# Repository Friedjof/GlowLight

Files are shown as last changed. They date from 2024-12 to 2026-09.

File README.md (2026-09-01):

# 🌟 GlowLight - Smart Wireless Bedside Lamp





A beautiful, smart bedside lamp with ESP-NOW wireless communication, gesture controls, and multiple lighting modes. Built on ESP32-C3 with 3D-printed components and WS2812B LED strips.

## 📋 Table of Contents

- [✨ Features](#-features)
- [🎭 Available Lighting Modes](#-available-lighting-modes)
- [📸 Gallery](#-gallery)
- [🔗 ESP-NOW Wireless Communication](#-esp-now-wireless-communication)
  - [Configuration](#configuration)
  - [🏠 Home Assistant](#-home-assistant)
- [🔧 Hardware Components](#-hardware-components)
  - [Main Components](#main-components)
  - [3D Printing](#3d-printing)
  - [Soldering](#soldering)
- [🚀 Quick Setup](#-quick-setup)
- [📦 Software Installation (Advanced)](#-software-installation-advanced)
- [👨‍💻 Development](#-development)
  - [Project Structure](#project-structure)
  - [Documentation](#documentation)
  - [Testing](#testing)
  - [Modes](#modes)
- [📄 License](#-license)

## ✨ Features

- **🎨 Multiple Lighting Modes**: Static colors, rainbow, beacon, candle effect, and more
- **⚡ ESP-NOW Communication**: Ultra-fast (<10ms) wireless synchronization between lamps
- **🔐 Encrypted Group Transport**: AES-256-GCM with a shared group key, authenticated peers and replay protection, up to 8 lamps per group
- **🔀 Per-Lamp Sync Control**: Follow and publish are independent switches, so a lamp can go its own way and rejoin later
- **🏠 Home Assistant**: Optional MQTT integration that announces its own entities, generated from the modes in the firmware
- **📶 Optional WiFi**: Infrastructure WiFi alongside ESP-NOW, with a captive portal for provisioning without reflashing
- **⬆️ Password-Protected OTA**: Firmware updates over WiFi with digest authentication and image verification
- **👋 Gesture Control**: Hand proximity sensing with VL53L0X distance sensor
- **🔘 Physical Controls**: Simple button interface for mode switching
- **🏠 3D Printable**: Complete STL files for custom lamp housing
- **🔧 Easy Setup**: One-command installation with interactive configuration
- **📱 Device Management**: Automatic ESP32 detection and flashing
- **💾 Backup System**: Configuration backup and restore

## 🎭 Available Lighting Modes

### Active Modes
- **🎨 StaticMode**: Single solid color with full brightness control
- **🌈 ColorPickerMode**: Cycle through color spectrum with distance sensor
- **🌈 RainbowMode**: Classic flowing rainbow effect with speed control
- **✨ RandomGlowMode**: 10-color random transitions with zen to party speeds
  - *NEW v3.3.0*: Enhanced with 10 scientifically distributed colors (every 36° in HSV space)
  - Features: Pause/transition cycles, inherited brightness control, mesh synchronization
  - Speed modes: Zen (meditative) → Normal → Lebendig (energetic) → Hektisch (party)

### Optional Modes
- **🕯️ CandleMode**: Realistic candle flicker simulation
- **🚨 BeaconMode**: Beacon/alert patterns for notifications
- **🌅 SunsetMode**: Natural sunset simulation for bedtime
- **💫 StrobeMode**: Synchronized strobe effects over ESP-NOW
- **🎮 MiniGame**: Interactive games using distance sensor

> **Note**: Mode selection is declared in `include/ModeConfig.h`. Set an individual
> `GLOW_ENABLE_*` switch to `1`, or use the `esp32c3-all-modes` build profile.

## 📸 Gallery

<table>
  <tr>
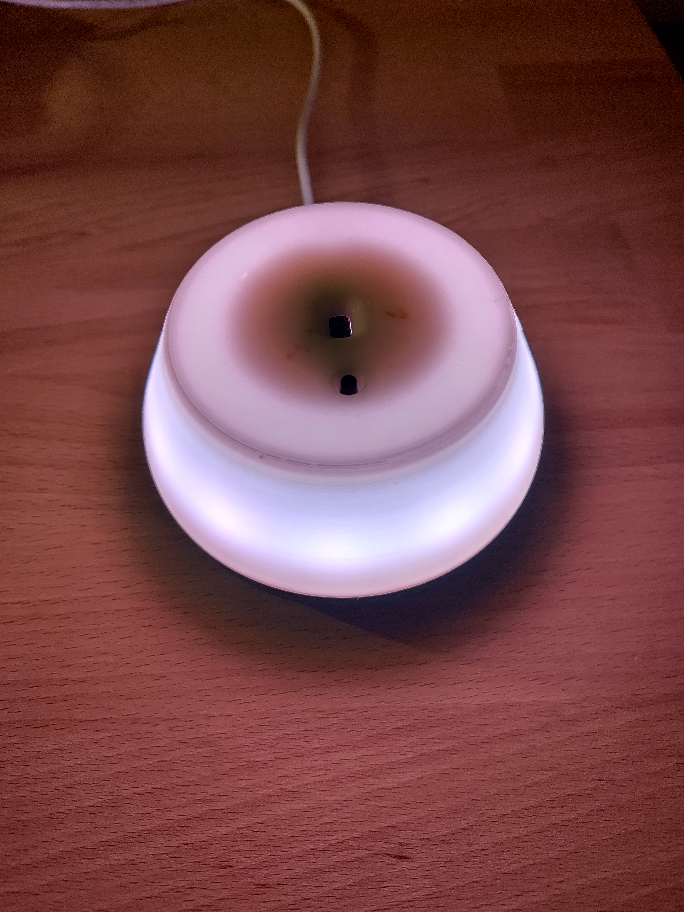
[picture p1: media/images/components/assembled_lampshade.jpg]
Assembled Lampshade
    <td></td>
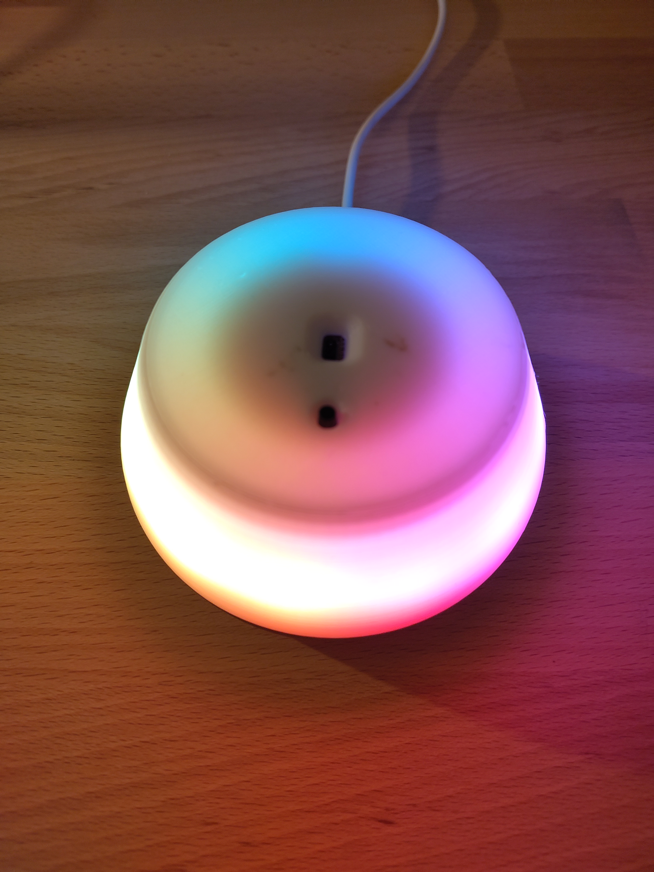
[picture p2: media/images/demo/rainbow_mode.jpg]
Rainbow Mode
    <td></td>
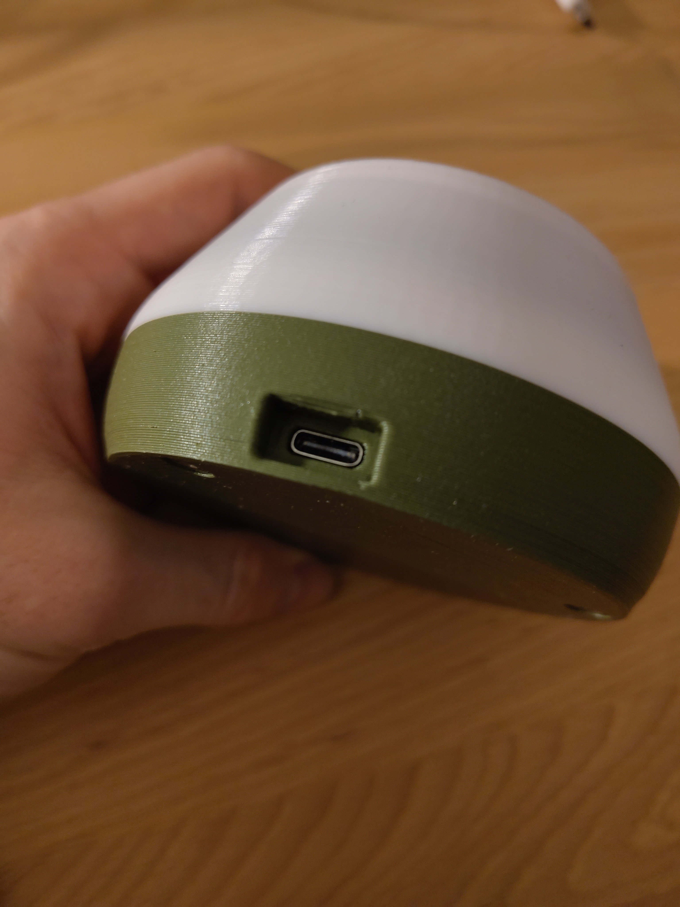
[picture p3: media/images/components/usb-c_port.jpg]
USB-C Port
    <td></td>
  </tr>
</table>

[-> Rainbow Mode Demo Video](media/images/demo/dual_lamps_rainbow_mode.mp4)

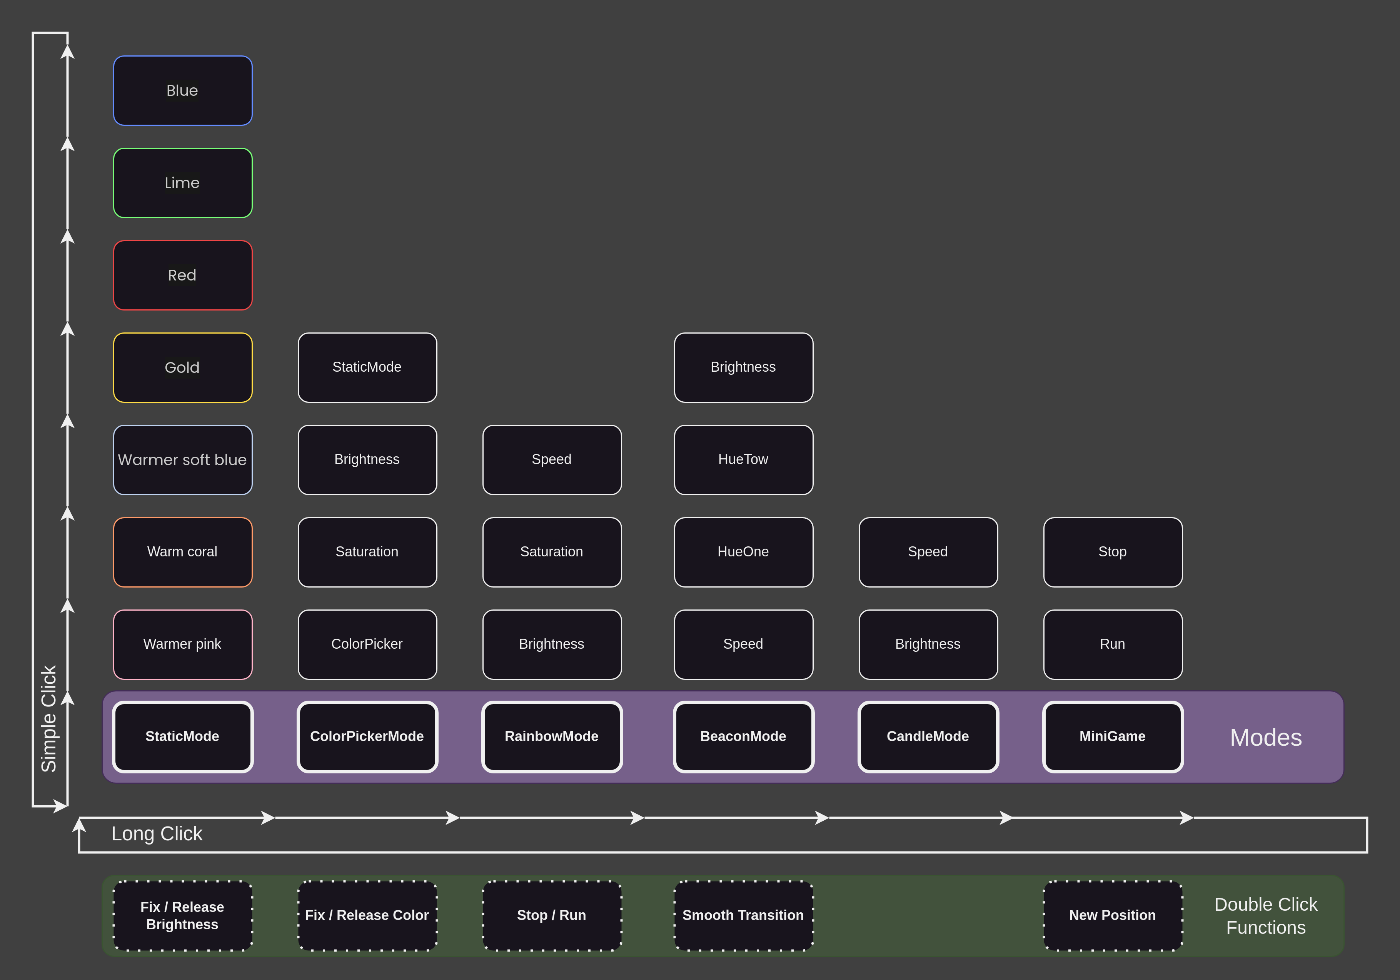
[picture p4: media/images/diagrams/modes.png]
Modes


This is an overview of the different modes available in the lamp. The modes can be toggled using the button.

## 🔗 ESP-NOW Wireless Communication

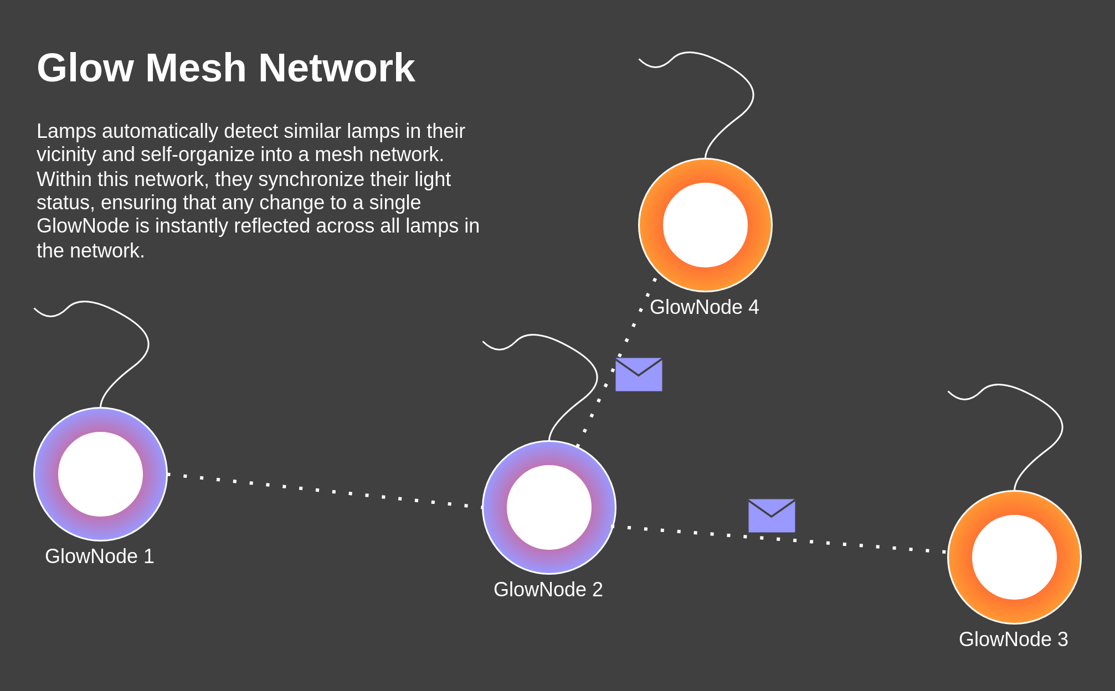
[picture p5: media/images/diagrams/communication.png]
Communication


[-> Wireless Synchronization Demo Video](media/images/demo/3_lamps_communication.mp4)

GlowLight uses **ESP-NOW** for ultra-fast, low-latency wireless communication between lamps. ESP-NOW provides direct device-to-device communication without requiring a WiFi router, enabling instant synchronization across multiple lamps.

### Why ESP-NOW?

- ⚡ **Ultra-low latency**: <10ms message delivery (vs 50-200ms with traditional mesh)
- 🔋 **Energy efficient**: Minimal power consumption compared to WiFi mesh
- 📡 **Simple setup**: No SSID/password configuration needed - just power on
- 🎯 **Reliable**: Direct broadcast communication, no routing overhead
- 📶 **Good range**: Up to 200m line-of-sight
- 🔐 **Encrypted**: AES-256-GCM with a shared group key, up to 8 lamps per group

### Configuration

ESP-NOW broadcasts are not encrypted by the radio, so GlowLight encrypts and
authenticates every frame itself. All lamps of a group share one 256-bit key,
which the setup generates for you:

```bash
./install.sh    # ESP-NOW section: "create" on the first lamp, "join" on the others
```

```cpp
#define WIFI_ON false                  // Optional infrastructure WiFi
#define WIFI_SSID ""
#define WIFI_PASSWORD ""
#define GLOW_HOSTNAME "glowlight"
#define GLOW_PORTAL_ENABLED false       // Hold button during boot to activate
#define GLOW_PORTAL_PASSWORD "..."      // Unique WPA2 password from setup
#define GLOW_OTA_ENABLED false          // Updates over infrastructure WiFi
#define GLOW_OTA_PASSWORD "..."         // Separate unique update password
#define ESPNOW_CHANNEL 1              // WiFi channel (1-13), configurable
#define GLOW_GROUP_KEY_HEX "..."      // 64 hex characters, provisioned by the setup
#define GLOW_MAX_GROUP_NODES 8
#define GLOW_SYNC_FOLLOW_DEFAULT true  // Apply incoming group changes
#define GLOW_SYNC_PUBLISH_DEFAULT true // Publish local group changes
```

`WIFI_ON` is optional; ESP-NOW works without an access point. With WiFi disabled
or unavailable, every lamp parks on `ESPNOW_CHANNEL`. While connected, the access
point dictates the shared radio channel, so all lamps in a group must remain on
the same current channel. Using one access point for all WiFi-enabled lamps is the
simplest guarantee. In a mixed group with WiFi disabled on some lamps, the access
point must use `ESPNOW_CHANNEL`. Reconnect attempts are spread out and, once the
AP channel is known, short and targeted so the fallback channel remains available
for ESP-NOW most of the time.

All lamps must also share the same group key. Lamps with different keys neither
discover nor control each other. Without a valid key wireless synchronization
stays disabled.

See [docs/security.md](docs/security.md) for the security model, key rotation and
migration from older, unencrypted firmware.

Validated NVS configuration overrides these compile-time values. The optional
captive portal is opened only by holding the hardware button during boot and
runs on the ESP-NOW fallback channel without disabling secure group transport.
See [docs/configuration.md](docs/configuration.md) for provisioning, persistence
and the redacted `glow.config/1` API.

Optional OTA updates are available at `http://<hostname>.local/update` only while
infrastructure WiFi is online and require Digest authentication. See
[docs/ota.md](docs/ota.md) for the upload procedure and security boundary.

### 🏠 Home Assistant

A lamp on the WiFi can publish itself to Home Assistant over MQTT and appears
with a light, a mode selector and one control per mode setting — all generated
from the modes the firmware was built with, so nothing has to be configured by
hand. A command from Home Assistant moves the whole lamp group by default. See
[docs/home-assistant.md](docs/home-assistant.md).

### How It Works

1. **Automatic Discovery**: Lamps announce themselves via heartbeat messages (every 10 seconds)
2. **Authentication**: A new lamp is only trusted after answering a fresh challenge, so recorded traffic cannot be replayed in
3. **Instant Sync**: State changes (mode, color, brightness) are broadcast instantly to all lamps in the group
4. **No Infrastructure**: No router, server, or internet connection required
5. **Resilient**: 30-minute timeout removes inactive lamps from the network

Following incoming changes and publishing local changes are independent runtime
controls. They can be changed through the local `glow.control/1`
`sync.configure` operation. Re-enabling follow first requests a versioned state
snapshot and blocks application publishing until the lamp has safely rejoined.
See [docs/control-api.md](docs/control-api.md) for the request and status format.

`NetworkService` owns WiFi mode, access-point reconnects and the shared radio
channel. `CommunicationService` keeps its ESP-NOW broadcast peer on channel `0`
(the radio's current channel) and immediately announces the node after every
stable channel change.

For technical details, see the [CommunicationService README](lib/CommunicationService/README.md).

## 🔧 Hardware Components

- DUBEUYEW ESP32-C3 Development Board Mini
- VL53L0X distance sensor
- Simple push button (height ≥ 6mm)
- WS2812B 5V LED strip (11 LEDs)
- External 5V power supply
- USB-C and some other necessary cables
- 3x M3 threaded insert
- 3x M3 screws

### Main Components

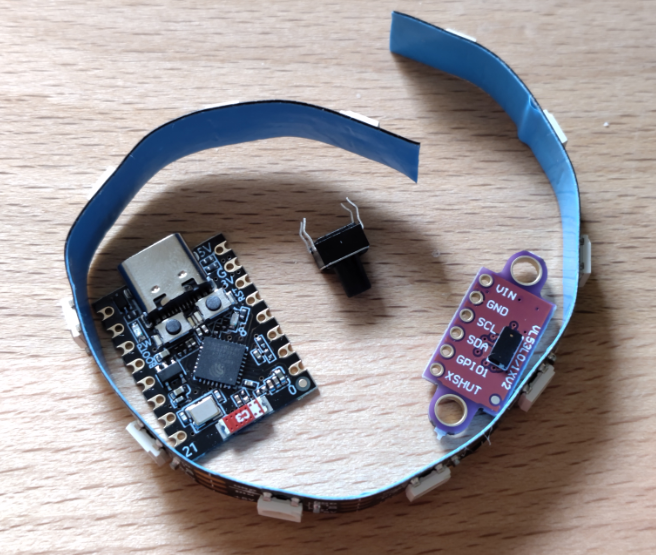
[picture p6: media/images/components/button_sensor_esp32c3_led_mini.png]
Main Components


### Tools and Materials

- 3D printer + filament (white and a color of your choice)
- Soldering iron + solder
- 2x Heat shrink tube
- Screwdriver

### 3D Printing

> You can find the 3D models in the [`/printing`](/printing) folder. The models are designed to be 3D printed and assembled. The lamp consists of three parts: the base, the lampshade, and the lampshade holder.

<table>
  <tr>
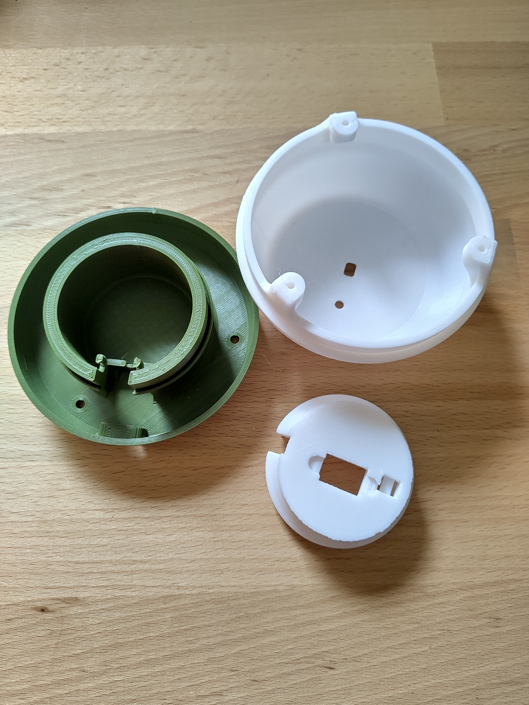
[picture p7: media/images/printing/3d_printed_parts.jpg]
Printed Parts
    <td></td>
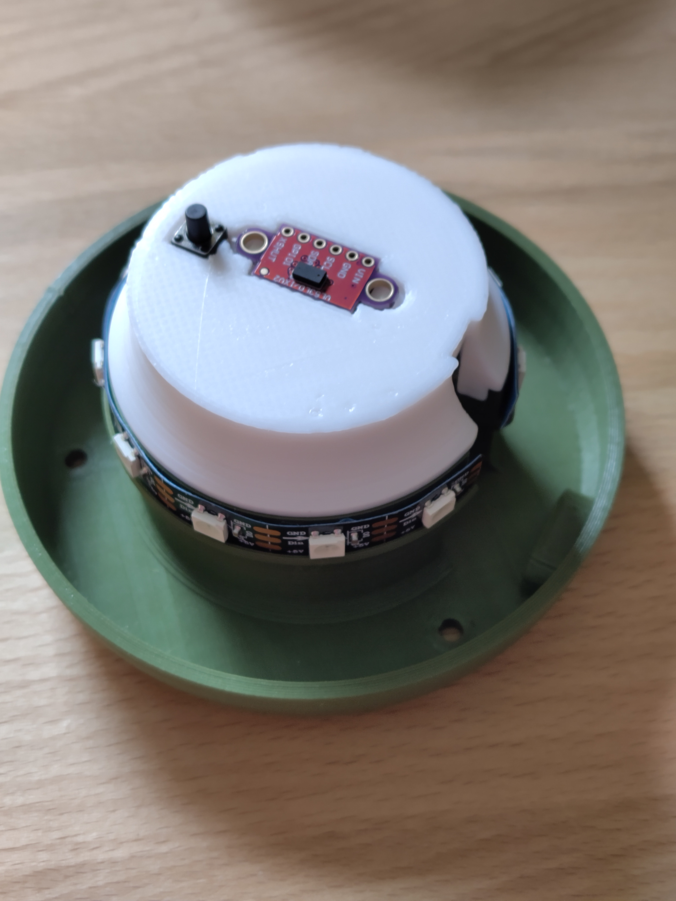
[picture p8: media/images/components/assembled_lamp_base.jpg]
Assembled Lamp Base
    <td></td>
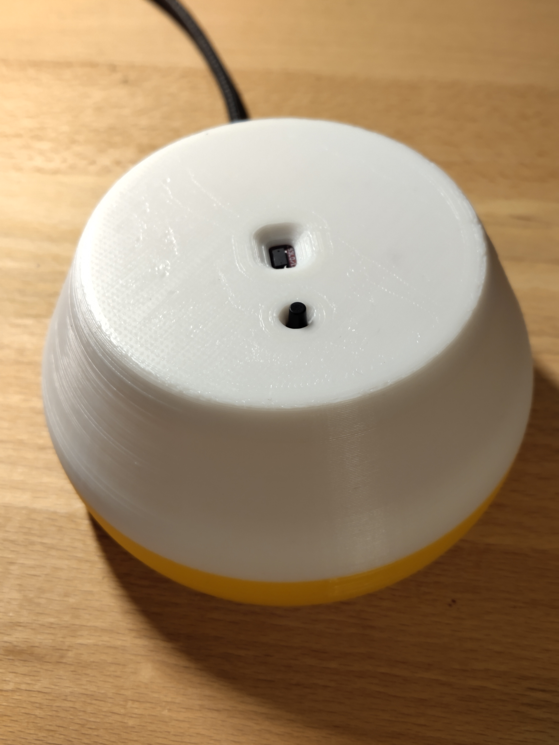
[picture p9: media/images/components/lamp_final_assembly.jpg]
Final Assembly
    <td></td>
  </tr>
</table>

### Soldering

The components are connected to the ESP32C3 using the following diagram:

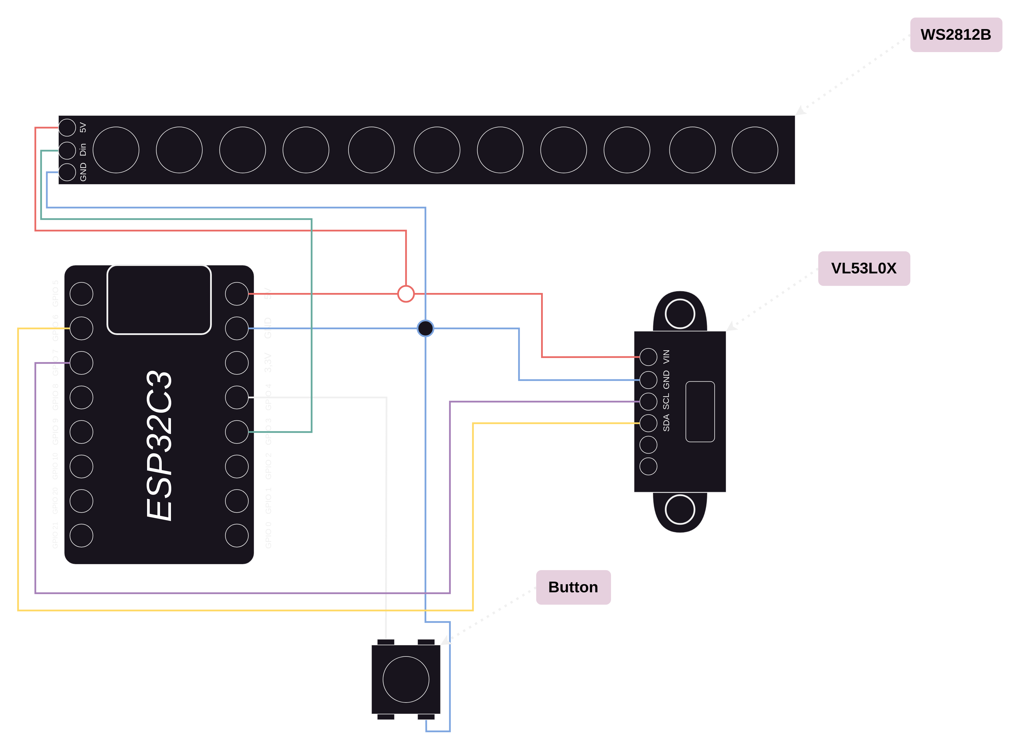
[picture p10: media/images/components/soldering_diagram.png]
Soldering Diagram


> The Button does not require a resistor, as the ESP32C3 has internal pull-up resistors.

This table also shows the connections:

| Component | Pin | ESP32C3 Pin |
| --- | --- | --- |
| Button | 1 | GND |
| | 2 | GPIO 4 |
| VL53L0X | VCC | 5V |
| | GND | GND |
| | SDA | GPIO 6 |
| | SCL | GPIO 7 |
| WS2812B | VCC | 5V |
| | GND | GND |
| | DI  | GPIO 3 |

> The `VL53L0X` is the distance sensor, the `WS2812B` is the LED strip, and the `Button` is the push button.

<table>
  <tr>
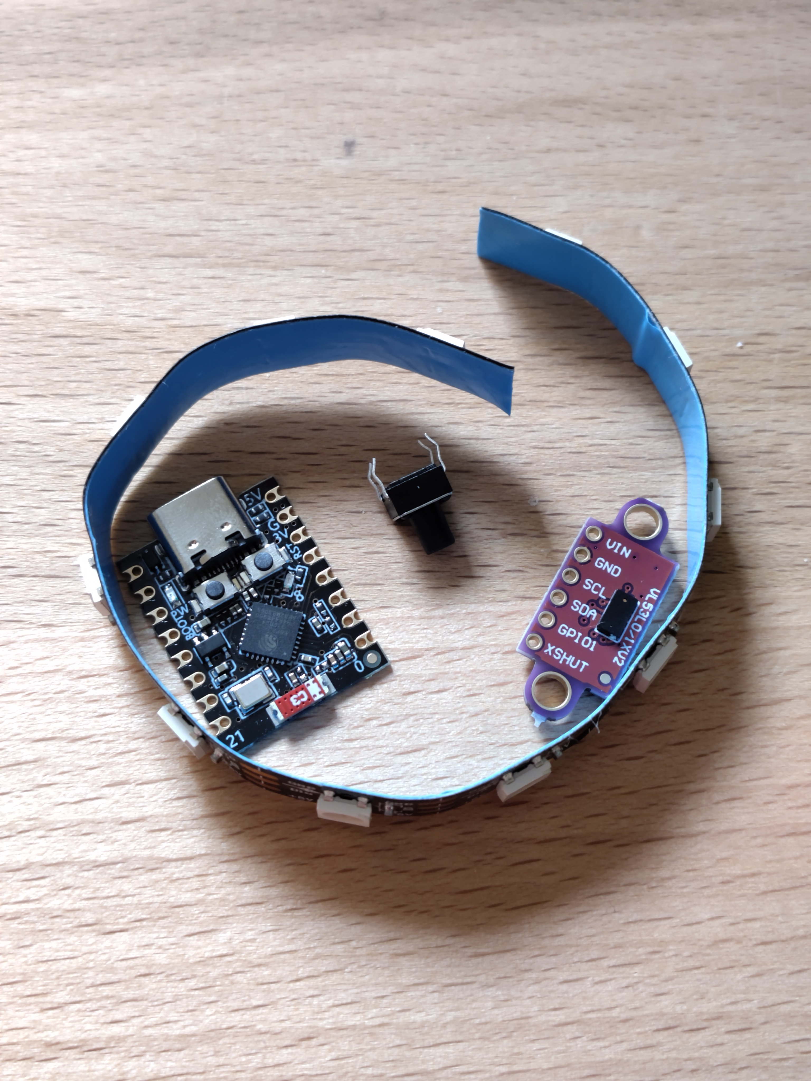
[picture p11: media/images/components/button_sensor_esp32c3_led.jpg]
Button, Sensor, ESP32C3, and LED
    <td></td>
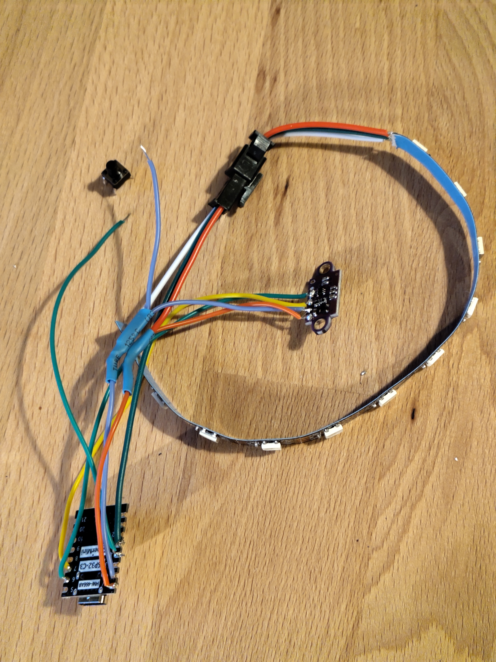
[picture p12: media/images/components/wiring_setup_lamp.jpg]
Wiring Setup
    <td></td>
  </tr>
</table>

### Threaded Insert

To attach the lampshade to the base, a threaded insert is used. The insert is placed in the base, and the lampshade is screwed onto it.

<table>
  <tr>
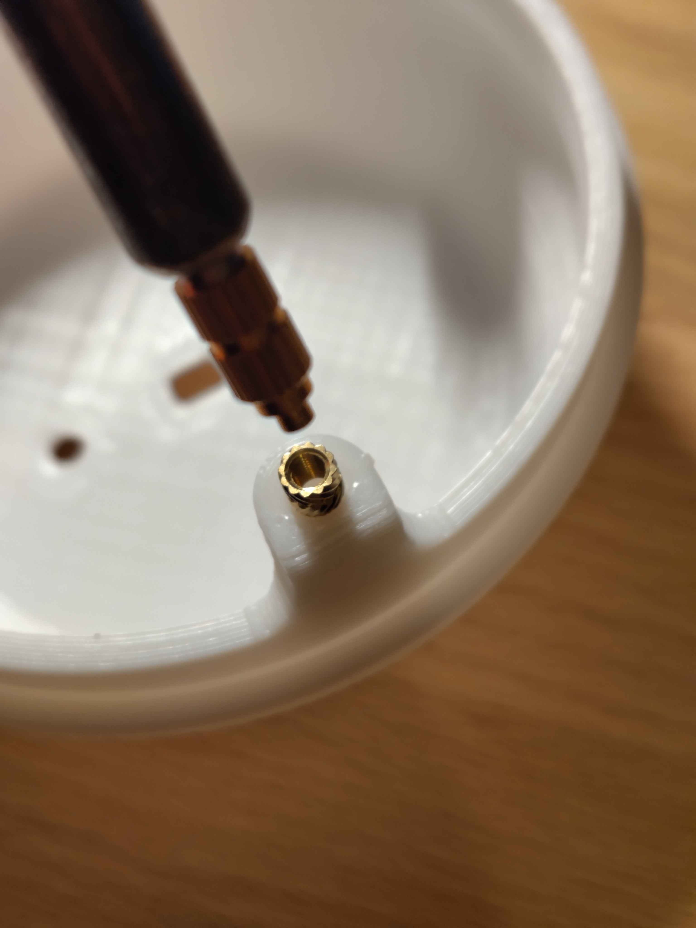
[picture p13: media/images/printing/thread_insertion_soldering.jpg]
Thread Insertion Soldering
    <td></td>
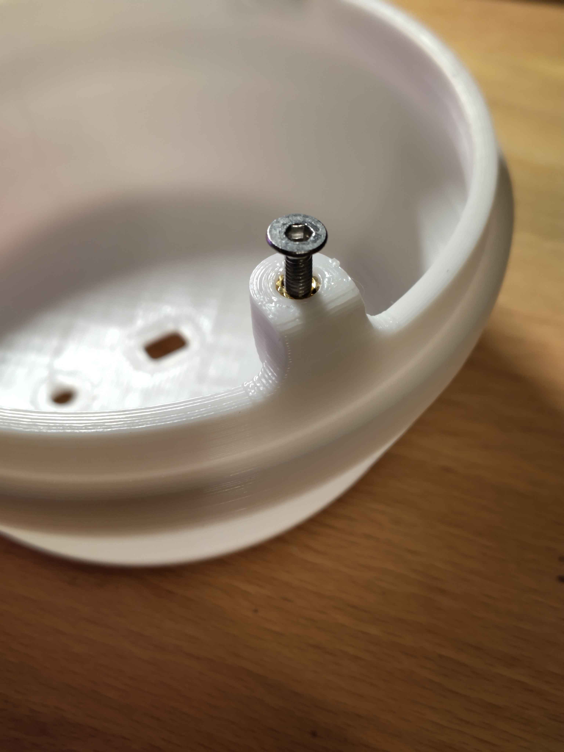
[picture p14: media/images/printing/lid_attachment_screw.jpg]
Lid Attachment Screw
    <td></td>
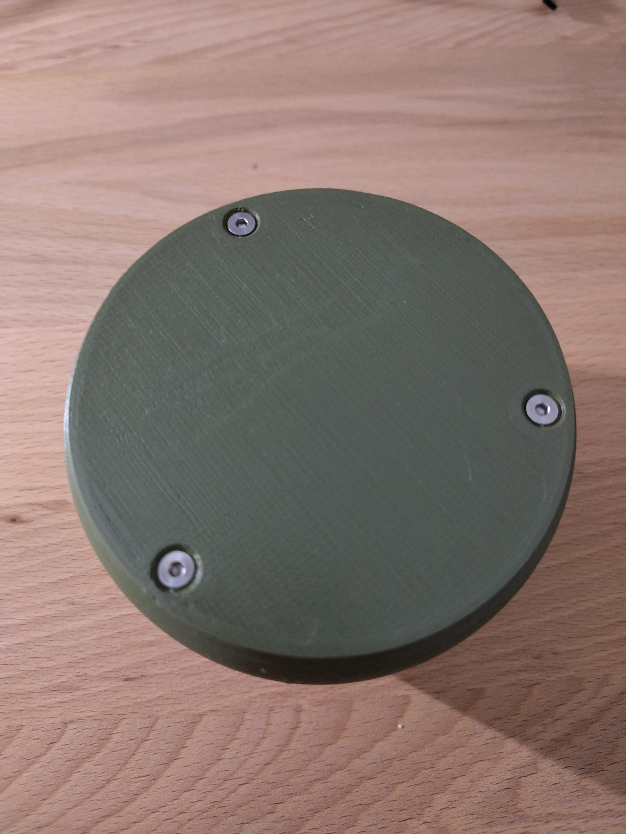
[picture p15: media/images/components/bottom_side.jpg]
Bottom Side
    <td></td>
  </tr>
</table>

## 🚀 Quick Setup

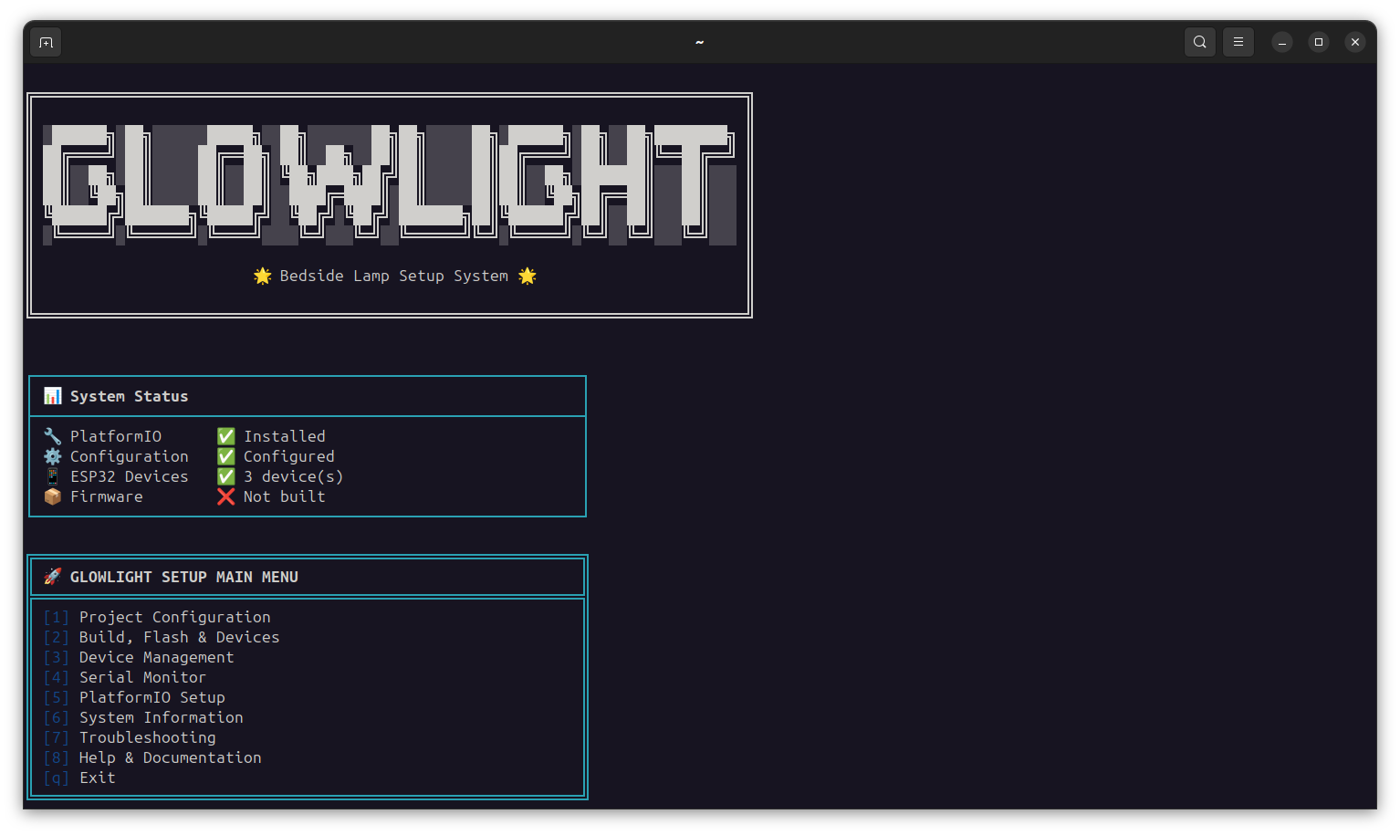
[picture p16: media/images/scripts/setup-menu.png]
Setup Script


**Get started in just one command!** The GlowLight setup system will guide you through the entire installation process:

```bash
curl -fsSL https://raw.githubusercontent.com/friedjof/GlowLight/main/install.sh > install.sh && bash install.sh
```

**Alternative download method:**
```bash
wget https://raw.githubusercontent.com/friedjof/GlowLight/main/install.sh && bash install.sh
```

### What the installer does:

1. **🔍 Checks system requirements** (Python 3.8+, Git)
2. **📦 Installs dependencies** automatically for your OS (Ubuntu/Debian, Fedora, Arch, macOS)
3. **📂 Downloads the GlowLight project** to `~/GlowLight` — unless you run the script from an existing checkout, which is then used as-is
4. **🛠️ Launches the interactive setup system** with a beautiful menu interface

### Interactive Setup Features:

- **⚙️ Project Configuration**: Guided wizards for the group key, captive portal, OTA, WiFi, Home Assistant and GPIO pins
- **🔨 Build & Flash**: Compile and upload firmware to your ESP32-C3 with one click
- **📱 Device Management**: Automatic ESP32 device detection and management
- **📺 Serial Monitor**: Real-time device monitoring with logging
- **🔧 PlatformIO Setup**: Automatic PlatformIO installation and management
- **💾 Backup System**: Configuration backup and restore functionality

### Manual Installation

If you prefer to set up manually:

```bash
# Clone the repository
git clone https://github.com/friedjof/GlowLight.git
cd GlowLight

# Run the setup system
python3 scripts/setup.py
```

## 📦 Software Installation (Advanced)

This is a PlatformIO project. The setup system above handles everything automatically, but for manual installation, PlatformIO must be installed. Once installed, you can open the project in PlatformIO and flash the software onto the ESP32C3.

Alternatively, a `Makefile` is included, allowing you to flash the software via the command line. For this, PlatformIO must be installed, and the `PLATFORMIO` environment variable should point to the PlatformIO executable.

If you're familiar with Nix-shell, you can use the [`shell.nix`](/shell.nix) file to set up the environment for PlatformIO.

### PlatformIO Commands

- `pio run`: Compiles the software
- `pio run --environment esp32c3-all-modes`: Compiles and links every mode
- `pio run --environment esp32c3-integration`: Build with the serial test console
- `pio run --target upload`: Flashes the software to the ESP32C3
- `pio run --target clean`: Removes compiled files
- `pio device monitor`: Opens a terminal to view the ESP32C3 output

### Makefile Commands

Building and flashing:

- `make` or `make build`: Compiles the standard profile
- `make build-all`: Compiles and links every mode
- `make build-profiles`: Builds all three profiles and checks each fits an OTA slot
- `make flash [device-number]`: Flashes the software to the ESP32-C3
- `make flash-all`: Flashes every connected lamp with the same image — this is what puts them into one group
- `make clean`: Removes compiled files
- `make monitor [device-number]`: Opens the serial monitor
- `make run [device-number]`: Flashes the software and opens the monitor
- `make list`: Lists matching ESP32-C3 serial devices

Testing without hardware:

- `make test`: Everything that runs on the host, about a second
- `make test-native`: Protocol, control API and configuration tests against the real firmware sources
- `make test-setup`: Setup, group key handling and the host-side frame format

Testing with hardware:

- `make test-integration`: Group synchronization across all connected lamps
- `make test-isolation`: Two lamps with different keys must ignore each other
- `make test-security KEY=<64 hex>`: Replay and tampering checks against one lamp
- `make test-ota PORT=… HOST=…`: Authenticated firmware update
- `make test-homeassistant BROKER=… DEVICE=… PORT=…`: MQTT integration against a broker

### Libraries Used

- [`ArrayList`](https://registry.platformio.org/libraries/braydenanderson2014/ArrayList) for dynamic arrays
- [`Button2`](https://registry.platformio.org/libraries/lennarthennigs/Button2) for button input handling
- [`Adafruit_VL53L0X`](https://github.com/adafruit/Adafruit_VL53L0X) for the distance sensor
- [`FastLED`](https://registry.platformio.org/libraries/fastled/FastLED) for LED control
- [`ArduinoJson`](https://registry.platformio.org/libraries/bblanchon/ArduinoJson) for message serialization
- [`PubSubClient`](https://registry.platformio.org/libraries/knolleary/PubSubClient) for the optional MQTT connection
- **ESP-NOW**, **WiFi**, **mDNS**, **WebServer**, **Preferences** and **Update** (built-in ESP32 libraries)

For more details on the libraries, refer to the [`platformio.ini`](/platformio.ini) file.

## 👨‍💻 Development

The software is written in C++ and is structured as a typical PlatformIO project. The main file is [`src/main.cpp`](/src/main.cpp), which wires the services together and contains the setup and loop functions. The modes, services, and the controller live in separate libraries under [`/lib`](/lib).

### Project Structure

`Controller` sits between the modes and everything that talks to the outside
world. It derives a machine-readable capability document from what the modes
declare and offers one transport-neutral command surface, so an adapter never
needs to know about a specific mode.

| Library | Responsibility |
|---|---|
| `Controller` | Mode lifecycle, capability document, `glow.control/1` operations, group synchronization policy |
| `AbstractMode`, `GlowRegistry` | Base class for modes; typed settings with bounds and defaults that everything else is generated from |
| `LightService`, `DistanceService` | LED output and the VL53L0X proximity sensor |
| `CommunicationService` | Encrypted ESP-NOW transport: handshake, replay protection, fragmentation |
| `NetworkService` | Owns the shared radio: WiFi state machine, fallback channel, mDNS |
| `ConfigService` | Validated device configuration and its persistence in NVS |
| `CaptivePortalService` | WPA2 setup access point for provisioning without reflashing |
| `OtaService` | Password-protected firmware updates over WiFi |
| `HomeAssistantService` | MQTT adapter; the pure mapping lives in `HomeAssistantProtocol` |

Adding a mode does not touch any of the services: declare its options and
registry keys as before, register it in `src/ModeRegistration.cpp`, and it shows
up in the control API and in Home Assistant on its own.

### Documentation

- [Control API](docs/control-api.md) — capability document and JSON command surface
- [Configuration](docs/configuration.md) — provisioning, NVS persistence, captive portal
- [Security](docs/security.md) — threat model, key handling, migration from older firmware
- [Home Assistant](docs/home-assistant.md) — MQTT integration, topics, entity generation
- [OTA Updates](docs/ota.md) — upload procedure and security boundary
- [Technical Diagrams](docs/diagrams.md) — architecture and flow diagrams

### Testing

`make test` runs everything that needs no hardware. The protocol tests compile
the real `CommunicationService` on the host against thin shims for Arduino,
ESP-NOW, FreeRTOS and mbedTLS, and drive it with frames built by an independent
implementation — so the firmware and the test oracle cannot drift apart quietly.

The hardware runners in [`test/hil`](/test/hil) cover group synchronization,
group isolation, replay and tampering, OTA and the Home Assistant integration.
See [test/README](/test/README) for what each one checks and what it needs.

### Technical Diagrams

For a comprehensive understanding of the GlowLight system architecture and operation, see the [Technical Diagrams](docs/diagrams.md) which includes:

- **[Class Diagram](docs/diagrams.md#class-diagram)**: Complete class structure and relationships
- **[Main Program Flow](docs/diagrams.md#main-program-flow)**: Startup sequence and main loop execution
- **[Mode System Flow](docs/diagrams.md#mode-system-flow)**: Lighting modes management and switching
- **[Service Integration Flow](docs/diagrams.md#service-integration-flow)**: LightService, DistanceService, and CommunicationService interaction
- **[Button Interaction Flow](docs/diagrams.md#button-interaction-flow)**: Button press handling and mode switching logic
- **[ESP-NOW Communication Flow](docs/diagrams.md#esp-now-communication-flow)**: Wireless networking and synchronization
- **[Available Modes Detail](docs/diagrams.md#available-modes-detail)**: Overview of all lighting modes and their features

### Modes

Every mode is a class that inherits from the `AbstractMode` class. The abstract class already implements the basic functions that every mode should have. In every mode, the following functions must be implemented: `setup`, `customFirst`, `customLoop`, `last`, and `customClick`.

- `setup`: This function is called once when the mode is added to the controller when the lamp is turned on.
- `customFirst`: This function is called once when the mode is newly selected.
- `customLoop`: This function is called every loop iteration.
- `last`: This function is called once when the mode is removed from the controller.
- `customClick`: This function is called when a double click is detected from the button.

The constructor sets `title` for display and `id` as the stable protocol
identifier. The ID appears in group messages, in the control API and in MQTT
topics, so it must not change once lamps are in the field; the display name may.

Everything a mode declares in `setup` is what the rest of the system works from:

- `registry.init(key, type, default, min, max)` defines a setting. Its type and
  bounds become validation for remote changes and, in Home Assistant, a number,
  a switch or a text field.
- `addOption(title, callback)` registers an option, which becomes a selectable
  entry both on the button and in the control API.
- `declareCommand(name, arguments)` exposes a mode-specific action that peers and
  adapters may invoke.

Optional hooks exist for modes that need to react to state arriving from
elsewhere: `onStateApplied` after a complete state was adopted,
`onSettingChanged` for a single value, and `onStateActivated` when the mode
becomes active with restored state. Simple modes need none of them.

## 📄 License

This project is licensed under the GNU General Public License v3.0. For more information, see the [`LICENSE`](/LICENSE) file.

---

## ⚠️ Beta Notice

This is a beta version of the project. The software is still under development, and the hardware may require some adjustments. I cannot guarantee that the project will work as expected and will not be responsible for any damage caused by the project.

## 🎯 Quick Start Reminder

**New to GlowLight?** Get started with just one command:

```bash
curl -fsSL https://raw.githubusercontent.com/friedjof/GlowLight/main/install.sh | bash
```

The setup system will guide you through everything! 🚀

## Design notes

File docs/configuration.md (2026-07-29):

# Runtime Configuration and Captive Portal

GlowLight loads network, radio, group and synchronization defaults from NVS at
boot. If NVS has no valid record, the values in `include/GlowConfig.h` are used.
If neither source validates, the firmware fails closed with infrastructure WiFi
and group communication disabled on fallback channel 1.

Hardware pins, compiled lighting modes, queue sizes and maximum group size remain
build-time configuration.

## Stored Configuration

The `glow.config` schema contains:

- infrastructure WiFi enabled state, SSID, password and hostname

Lamps are usually flashed from one shared configuration, so a hostname left at its
default is not unique. Each lamp therefore appends the last three bytes of its MAC,
giving names like `glowlight-52c82c`. It announces the result as
`Reachable as <name>.local`, and that name is also the device name in Home Assistant.
A hostname entered in the captive portal belongs to that one lamp and is used as
given.
- ESP-NOW fallback channel
- secure group communication enabled state and 256-bit group key
- default `follow` and `publish` synchronization policy
- OTA enabled state and write-only OTA password

The `PreferencesConfigStore` keeps two CRC-protected slots in the `glowcfg` NVS
namespace. A save writes the older slot with a higher generation and verifies it
before reporting success. At boot the highest valid generation wins; a corrupt or
partially written slot is ignored as a whole.

NVS persistence does not imply flash encryption. A person with physical flash
access can recover stored WiFi, group and OTA credentials unless ESP32 flash/NVS
encryption is enabled for the product.

## Opening the Portal

The installer can enable the portal and generates an individual WPA2 password.
With the feature enabled:

1. Disconnect power from the lamp.
2. Hold the lamp button.
3. Apply power and keep the button held during boot.
4. Join `<hostname>-setup` using the generated portal password.
5. Open `http://192.168.4.1/` if the operating system does not open the captive
   page automatically. The actual address is printed on the serial console.

The portal never opens merely because an infrastructure access point is down and
automatically restarts the lamp after ten minutes.
It runs in `WIFI_AP_STA` mode on the configured fallback channel, leaves modem
sleep disabled and does not deinitialize ESP-NOW. Existing secure group
communication therefore remains available to lamps on the same channel.

An ESP32-C3 has one radio. A peer connected to an infrastructure access point on
a different channel cannot communicate with the provisioning lamp until both are
again on the same channel.

## Configuration API

The portal exposes `glow.config/1` only while the physically activated setup AP
is running:

```text
GET  /api/config
POST /api/config
POST /api/factory-reset
```

`GET /api/config` returns redacted state and a per-boot CSRF `sessionToken`. WiFi
passwords and group keys are never returned. Mutating requests require that token
in the `X-Glow-Token` header. Access authentication is provided by the individual
WPA2 portal password; the token prevents cross-origin form submission. An empty
password or key field preserves the stored secret.

```json
{
  "api": "glow.config/1",
  "wifi": {
    "enabled": true,
    "ssid": "home",
    "password": "write-only",
    "hostname": "glow-bedroom"
  },
  "radio": {"fallbackChannel": 6},
  "group": {
    "enabled": true,
    "key": "64 hexadecimal characters, write-only",
    "follow": true,
    "publish": true
  },
  "ota": {"enabled": true, "password": "write-only"}
}
```

Updates are validated and stored atomically, then the lamp restarts. Active
WiFi credentials and group keys are never replaced live. Factory reset clears
NVS overrides and restarts into the compile-time configuration.

The portal deliberately does not expose `Controller::executeControl()`. The
configuration AP and session token protect provisioning, but are not a general
authorization mechanism for lamp control.

OTA credentials are independent from the portal credentials. An empty OTA
password preserves the existing value. See [ota.md](ota.md) for update behavior
and its trusted-network security boundary.

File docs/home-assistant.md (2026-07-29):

# Home Assistant

A lamp on the infrastructure WiFi can publish itself to Home Assistant over MQTT.
It announces its own entities, so nothing has to be configured in Home Assistant
by hand, and no YAML is involved.

## What you need

- The lamp joined to your WiFi (see [configuration.md](configuration.md))
- An MQTT broker Home Assistant already talks to, usually the Mosquitto add-on
- The MQTT integration enabled in Home Assistant

## Enabling it

Either in the setup before flashing:

```bash
./install.sh     # step "Home Assistant"
```

or later through the captive portal, which stores the settings in NVS and needs
no reflash. Both ask for broker host, port, optional credentials and the
discovery prefix (`homeassistant` unless you changed it in Home Assistant).

Home Assistant requires infrastructure WiFi. Enabling MQTT without WiFi is
rejected by the configuration validator rather than silently ignored.

## What appears

Every lamp becomes one device, identified by `glow-<node id>`, which is derived
from its MAC. Device id, base topic, MQTT client id and every entity id are
therefore unique even though all lamps are flashed from the same configuration.

The device **name** follows the hostname, which for the same reason gets the last
three MAC bytes appended unless you named the lamp yourself in the portal. So the
lamps appear as `glowlight-52c82c`, `glowlight-9d6fc0` and so on. Rename them in
Home Assistant to whatever suits the room; that only changes the display name.

The entities are generated from what the modes declare, so a firmware with more
modes simply offers more entities:

| Entity | Comes from |
|---|---|
| Light (on/off, brightness) | the `brightness` value every mode inherits |
| Mode (select) | the list of modes in the firmware |
| *Mode* option (select) | the options a mode registered, one entity per mode |
| One control per setting | every writable registry key of a mode |
| Follow group, Publish to group (switches) | the two synchronization controls |
| Sync status (sensor) | the runtime synchronization state |

An integer setting becomes a number with the declared minimum and maximum, a
boolean becomes a switch, a string becomes a text field. Entities that belong to
a mode are marked unavailable while another mode is active, so the dashboard only
shows what is actually adjustable right now.

The full state document is published to `glowlight/<device>/state` and attached
to the sync status sensor as attributes, which is the place to look when you want
to template on something that has no entity of its own.

### Colour

The light entity carries brightness only. Colour differs too much between modes —
one mode has an RGB value, another has hue and saturation — so it is exposed as
the individual settings of the active mode rather than guessed into one entity.
A template light in Home Assistant can combine them if you want a single control.

## Groups

By default a command from Home Assistant applies to the whole lamp group: change
the mode on one lamp and the others follow over ESP-NOW. That only happens while
the lamp is actually synchronized and allowed to publish. If it is detached, or
still joining, the command applies to that lamp alone instead of failing. The
`Follow group` and `Publish to group` switches decide which of the two it is.

This means one lamp is enough to control a whole group from Home Assistant. If
you want each lamp separately, switch `Publish to group` off on the lamps that
should keep to themselves.

## Topics

```
glowlight/<device>/status                     online | offline (last will)
glowlight/<device>/state                      full state document
glowlight/<device>/light/state | /set
glowlight/<device>/mode/state  | /set
glowlight/<device>/mode/<mode>/available
glowlight/<device>/option/<mode>/state | /set
glowlight/<device>/setting/<mode>/<key>/state | /set
glowlight/<device>/sync/follow/state  | /set
glowlight/<device>/sync/publish/state | /set
glowlight/<device>/sync/status
```

`<device>` is `glow-<node id>`. Discovery documents are retained under
`<discovery prefix>/<component>/<device>/<object>/config`.

## Security

- Broker credentials live in NVS once set through the portal, not in the image.
- The group key, the OTA password and the broker password are never published;
  a test asserts that no generated payload contains them.
- MQTT itself is unauthenticated towards the lamp: anyone who can publish to the
  broker can control the lamp. Restrict broker access accordingly — the lamp
  trusts the broker the same way it trusts the local network for OTA.
- The connection is plain MQTT. Use it on a network you control.

## Limitations

- Reconnecting to an unreachable broker briefly blocks the main loop, because the
  MQTT client connects synchronously. The retry interval backs off to a minute,
  so a broker that is down causes a short hitch at most once per minute.
- Discovery is published once per connection. If you delete entities in Home
  Assistant, restart the lamp to have them announced again.

## Testing

```bash
pip install paho-mqtt
make test-homeassistant BROKER=mqtt.local DEVICE=glow-1384610827 PORT=/dev/ttyACM0
```

Add `PEER_PORT=/dev/ttyACM1` to also verify that a command sent to one lamp
reaches the second one over ESP-NOW.

The mapping itself is covered by host tests in `test/native/tests_homeassistant.cpp`,
including a mode the MQTT layer has never heard of, which has to appear in
discovery with its options and settings anyway.

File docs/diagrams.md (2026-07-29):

# GlowLight - Technical Diagrams

This document contains all technical diagrams for the GlowLight Smart Mesh Bedside Lamp project, including class relationships and program flow visualizations.

## Table of Contents

- [Class Diagram](#class-diagram)
- [Program Flow Diagrams](#program-flow-diagrams)
  - [Main Program Flow](#main-program-flow)
  - [Mode System Flow](#mode-system-flow)
  - [Service Integration Flow](#service-integration-flow)
  - [Button Interaction Flow](#button-interaction-flow)
  - [Mesh Communication Flow](#mesh-communication-flow)
  - [Available Modes Detail](#available-modes-detail)

## Class Diagram

This diagram shows the complete class structure and relationships within the GlowLight system.

```mermaid
classDiagram
    %% Main entry point
    class main {
        +Controller controller
        +LightService lightService
        +CommunicationService communicationService
        +DistanceService distanceService
        +GlowRegistry glowRegistry
        +setup()
        +loop()
    }

    %% Core Controller
    class Controller {
        -LightService* lightService
        -CommunicationService* communicationService
        -DistanceService* distanceService
        -GlowRegistry* glowRegistry
        -bool isButtonPressed
        -unsigned long lastButtonTime
        +setup(LightService*, CommunicationService*, DistanceService*, GlowRegistry*)
        +loop()
    }

    %% Services
    class LightService {
        -CRGB leds[LED_NUM_LEDS]
        -CRGB currentLeds[LED_NUM_LEDS]
        -uint8_t hardwareBrightness
        -uint16_t lightUpdateSteps
        -bool outputDirty
        +setup()
        +loop()
        +setHardwareBrightness(uint8_t)
        +fill(CRGB)
        +setLed(uint8_t, CRGB)
        +fillImmediate(CRGB)
        +setLedImmediate(uint8_t, CRGB)
    }

    class CommunicationService {
        -bool connected
        -uint8_t peerList[MAX_PEERS][6]
        -int peerCount
        +setup()
        +loop()
        +sendAlert(Alert*)
        +scanForPeers()
        -setupESPNow()
        -addPeer()
    }

    class DistanceService {
        +setup()
        +getDistance()
    }

    class GlowRegistry {
        -AbstractMode* modes[MAX_MODES]
        -const char* modeNames[MAX_MODES]
        -int modeCount
        -int currentModeIndex
        -Preferences preferences
        +setup()
        +registerMode(const char*, AbstractMode*)
        +getMode(const char*)
        +getNextMode()
        +setCurrentMode(int)
        +getCurrentModeName()
    }

    %% Abstract Mode Interface
    class AbstractMode {
        <<abstract>>
        #uint8_t desiredBrightness
        +updateBrightnessFromSensor()
        +setDesiredBrightness(uint8_t)
        +getDesiredBrightness()
        +setup()*
        +customLoop()*
    }

    %% Concrete Mode Implementations
    class StaticMode {
        +setup()
        +update(CRGB*, int)
        +reset()
    }

    class RainbowMode {
        -uint8_t hue
        -uint8_t deltaHue
        +setup()
        +update(CRGB*, int)
        +reset()
    }

    class CandleMode {
        +setup()
        +update(CRGB*, int)
        +reset()
    }

    class RandomGlowMode {
        +setup()
        +update(CRGB*, int)
        +reset()
    }

    class SunsetMode {
        +setup()
        +update(CRGB*, int)
        +reset()
    }

    class StrobeMode {
        +setup()
        +update(CRGB*, int)
        +reset()
    }

    class BeaconMode {
        +setup()
        +update(CRGB*, int)
        +reset()
    }

    class ColorPickerMode {
        +setup()
        +update(CRGB*, int)
        +reset()
    }

    %% Helper Classes
    class Alert {
        -AlertType type
        -char message[256]
        -unsigned long timestamp
        +Alert(AlertType, const char*)
        +getType()
        +getMessage()
        +getTimestamp()
    }

    %% Relationships
    main --> Controller : creates
    main --> LightService : creates
    main --> CommunicationService : creates
    main --> DistanceService : creates
    main --> GlowRegistry : creates

    Controller --> LightService : uses
    Controller --> CommunicationService : uses
    Controller --> DistanceService : uses
    Controller --> GlowRegistry : uses

    LightService --> AbstractMode : uses current mode
    CommunicationService --> Alert : sends/receives
    GlowRegistry --> AbstractMode : manages all modes

    AbstractMode <|-- StaticMode : implements
    AbstractMode <|-- RainbowMode : implements
    AbstractMode <|-- CandleMode : implements
    AbstractMode <|-- RandomGlowMode : implements
    AbstractMode <|-- SunsetMode : implements
    AbstractMode <|-- StrobeMode : implements
    AbstractMode <|-- BeaconMode : implements
    AbstractMode <|-- ColorPickerMode : implements
```

## Program Flow Diagrams

### Main Program Flow

This diagram shows the complete program execution from system startup through the main loop.

```mermaid
flowchart TD
    A[System Start] --> B[setup Function]
    B --> C[Serial.begin 115200]
    C --> D[Wire.begin I2C Setup]
    D --> E[Services Setup]
    E --> E1[lightService.setup]
    E --> E2[distanceService.setup]
    E --> E3[networkService.setup]
    E --> E4[communicationService.setup]
    E1 --> F[Button Setup]
    E2 --> F
    E3 --> F
    E4 --> F
    F --> F1[button.begin BUTTON_PIN]
    F1 --> F2[button.setLongClickTime 500]
    F2 --> G[Mode Registration]
    G --> G1[controller.addMode staticMode]
    G1 --> G2[controller.addMode colorPickerMode]
    G2 --> G3[controller.addMode rainbowMode]
    G3 --> G4[controller.addMode randomGlowMode]
    G4 --> H[Alert Mode Setup]
    H --> H1[controller.setAlertMode alertMode]
    H1 --> I[controller.setup]
    I --> J[Button Handler Setup]
    J --> J1[setLongClickHandler nextMode]
    J1 --> J2[setClickHandler nextOption]
    J2 --> J3[setDoubleClickHandler customClick]
    J3 --> K[Setup Complete]
    K --> L[loop Function Infinite Loop]
    L --> M[Service Loop Calls]
    M --> M1[button.loop]
    M --> M2[controller.loop]
    M --> M3[lightService.loop]
    M --> M4[distanceService.loop]
    M --> M5[networkService.loop]
    M --> M6[communicationService.loop]
    M1 --> N{Button Event?}
    M2 --> O{Distance Change?}
    M3 --> P{LED Update?}
    M4 --> Q{Mesh Message?}
    M5 --> R[Update LEDs]
    N -->|Long Click| N1[controller.nextMode]
    N -->|Single Click| N2[controller.nextOption]
    N -->|Double Click| N3[controller.customClick]
    N -->|No Event| R
    O -->|Yes| O1[Process Distance Data]
    O -->|No| R
    O1 --> O2{ColorPicker Mode?}
    O2 -->|Yes| O3[Update Color Based on Distance]
    O2 -->|No| R
    P -->|Yes| P1[FastLED.show]
    P -->|No| R
    Q -->|Yes| Q1[Process Mesh Data]
    Q -->|No| R
    Q1 --> Q2[Synchronize with Other Lamps]
    N1 --> R
    N2 --> R
    N3 --> R
    O3 --> R
    P1 --> R
    Q2 --> R
    R --> L
```

### Mode System Flow

This diagram illustrates how lighting modes are managed, switched, and executed.

```mermaid
flowchart TD
    A[Mode System Start] --> B[Controller Setup]
    B --> C[Mode Array Initialization]
    C --> D[Current Mode = staticMode]
    D --> E{Button Long Click?}
    E -->|Yes| F[controller.nextMode]
    E -->|No| G{Button Single Click?}
    F --> F1[currentModeIndex++]
    F1 --> F2{Index >= modeCount?}
    F2 -->|Yes| F3[currentModeIndex = 0]
    F2 -->|No| F4[Switch to New Mode]
    F3 --> F4
    F4 --> F5[oldMode.last]
    F5 --> F6[newMode.setup]
    F6 --> F7[newMode.customFirst]
    F7 --> H[Mode Active]
    G -->|Yes| I[controller.nextOption]
    G -->|No| J{Button Double Click?}
    I --> I1[currentMode.nextOption]
    I1 --> H
    J -->|Yes| K[controller.customClick]
    J -->|No| H
    K --> K1[currentMode.customClick]
    K1 --> H
    H --> L[Mode Loop Execution]
    L --> L1[currentMode.customLoop]
    L1 --> L2[Update LEDs]
    L2 --> M{Distance Sensor Active?}
    M -->|Yes| N[Process Distance Input]
    M -->|No| O{Mesh Message?}
    N --> N1{ColorPicker Mode?}
    N1 -->|Yes| N2[Map Distance to Color]
    N1 -->|No| O
    N2 --> O
    O -->|Yes| P[Synchronize Mode State]
    O -->|No| Q[Continue Loop]
    P --> Q
    Q --> E
```

### Service Integration Flow

This diagram shows how the three core services interact with each other and the controller.

```mermaid
flowchart TD
    A[Service Integration] --> B[LightService]
    A --> C[DistanceService]
    A --> D[CommunicationService]
    B --> B1[FastLED Setup]
    B1 --> B2[LED Array Initialization]
    B2 --> B3[Default Brightness Setup]
    B3 --> B4{Mode Update Required?}
    B4 -->|Yes| B5[Update LED Colors]
    B4 -->|No| B6[FastLED.show]
    B5 --> B6
    B6 --> B7[Wait for Next Update]
    B7 --> B4
    C --> C1[VL53L0X Sensor Setup]
    C1 --> C2[I2C Communication Setup]
    C2 --> C3{Distance Reading Request?}
    C3 -->|Yes| C4[Read Sensor Data]
    C3 -->|No| C5[Wait]
    C4 --> C6[Process Distance Value]
    C6 --> C7{Valid Reading?}
    C7 -->|Yes| C8[Return Distance]
    C7 -->|No| C9[Return Error Value]
    C8 --> C5
    C9 --> C5
    C5 --> C3
    D --> D1[ESP-NOW Setup]
    D1 --> D2[Mesh Network Join]
    D2 --> D3[Peer Discovery]
    D3 --> D4{Mesh Message Received?}
    D4 -->|Yes| D5[Parse Message]
    D4 -->|No| D6{Send Message Required?}
    D5 --> D7{Mode Sync Message?}
    D7 -->|Yes| D8[Update Local Mode]
    D7 -->|No| D9[Process Other Message]
    D8 --> D6
    D9 --> D6
    D6 -->|Yes| D10[Broadcast to Mesh]
    D6 -->|No| D11[Continue]
    D10 --> D11
    D11 --> D4
    B8[LED Update Event] --> E[Controller Integration]
    C10[Distance Change Event] --> E
    D12[Mesh Sync Event] --> E
    E --> F{Event Type?}
    F -->|LED Update| G[Update Current Mode Display]
    F -->|Distance Change| H[Process Distance for Current Mode]
    F -->|Mesh Sync| I[Synchronize Mode State]
    G --> J[Services Continue]
    H --> J
    I --> J
    J --> B4
    J --> C3
    J --> D4
```

### Button Interaction Flow

This diagram details the button press handling and resulting actions.

```mermaid
flowchart TD
    A[Button Press Detected] --> B{Button Type?}
    B -->|Long Click 500ms+| C[nextMode]
    B -->|Single Click| D[nextOption]
    B -->|Double Click| E[customClick]
    C --> C1[Increment Mode Index]
    C1 --> C2{Index Overflow?}
    C2 -->|Yes| C3[Reset to First Mode]
    C2 -->|No| C4[Select New Mode]
    C3 --> C4
    C4 --> C5[Call currentMode.last]
    C5 --> C6[Call newMode.setup]
    C6 --> C7[Call newMode.customFirst]
    C7 --> F[Mode Switched]
    D --> D1[Call currentMode.nextOption]
    D1 --> D2[Mode-Specific Option Change]
    D2 --> G[Option Changed]
    E --> E1[Call currentMode.customClick]
    E1 --> E2[Mode-Specific Custom Action]
    E2 --> H[Custom Action Executed]
    F --> I[Continue Loop]
    G --> I
    H --> I
    I --> A
```

### Mesh Communication Flow

This diagram shows the ESP-NOW mesh networking and synchronization process.

```mermaid
flowchart TD
    A[Mesh Communication Start] --> B[ESP-NOW Initialization]
    B --> C[Peer Discovery]
    C --> D[Network Formation]
    D --> E{Message Type?}
    E -->|Incoming| F[Receive Message]
    E -->|Outgoing| G[Send Message]
    E -->|None| H[Idle State]
    F --> F1[Parse Message Header]
    F1 --> F2{Message Type?}
    F2 -->|Mode Sync| F3[Synchronize Mode]
    F2 -->|Alert| F4[Process Alert]
    F2 -->|Status| F5[Update Status]
    F3 --> I[Apply Changes]
    F4 --> I
    F5 --> I
    G --> G1[Prepare Message]
    G1 --> G2[Add Timestamp]
    G2 --> G3[Broadcast to Peers]
    G3 --> J[Message Sent]
    H --> K[Monitor Network]
    K --> L{Network Change?}
    L -->|Yes| C
    L -->|No| E
    I --> M[Update Local State]
    J --> N[Wait for ACK]
    M --> E
    N --> O{ACK Received?}
    O -->|Yes| E
    O -->|No| P[Retry Send]
    P --> G1
```

### Available Modes Detail

This diagram provides an overview of all available lighting modes and their features.

```mermaid
flowchart TD
    A[Available Modes] --> B[StaticMode]
    A --> C[ColorPickerMode] 
    A --> D[RainbowMode]
    A --> E[RandomGlowMode]
    A --> F[Alert Mode]
    
    G[Commented Modes] --> H[BeaconMode]
    G --> I[CandleMode]
    G --> J[SunsetMode]
    G --> K[StrobeMode]
    G --> L[MiniGame]
    
    B --> B1[Single Solid Color]
    B --> B2[Brightness Control]
    B --> B3[Color Selection via Distance]
    
    C --> C1[Distance-Based Color Selection]
    C --> C2[Real-time Color Change]
    C --> C3[Smooth Color Transitions]
    
    D --> D1[Flowing Rainbow Effect]
    D --> D2[Adjustable Speed]
    D --> D3[Mesh Synchronization]
    
    E --> E1[10 Scientific Colors]
    E --> E2[Speed Modes Zen to Party]
    E --> E3[Pause and Transition Cycles]
    
    F --> F1[System Notifications]
    F --> F2[Error Indicators]
    F --> F3[Status Communication]

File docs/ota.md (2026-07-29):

# Password-Protected OTA

GlowLight can install PlatformIO firmware images over infrastructure WiFi. OTA is
disabled by default and uses a credential that is separate from the captive
portal password.

## Enabling OTA

The installer can generate a unique OTA password, or OTA can be enabled later
through the physically activated captive portal. The fixed username is
`glowlight`; the password must contain 12-63 characters.

```cpp
#define GLOW_OTA_ENABLED true
#define GLOW_OTA_PASSWORD "a-unique-password"
```

Validated NVS values override these compile-time defaults. Existing version-1
NVS configuration is migrated to schema version 2 with OTA disabled.

OTA starts only after `NetworkService` reaches the `Online` state. It is never
bound in captive-portal mode and stops immediately when the infrastructure WiFi
connection is lost. After reconnect it starts again automatically.

## Installing Firmware

1. Build the profile intended for the lamp, for example `make build`.
2. Open `http://<hostname>.local/update` on the same trusted network.
3. Authenticate as `glowlight` with the generated OTA password.
4. Upload `.pio/build/esp32c3/firmware.bin`.
5. Wait for the success response and automatic restart.

The server uses HTTP Digest authentication so the password is not sent directly
as HTTP Basic credentials. Each authenticated update page also creates a one-time
upload token, and the HTTP server is recreated after every reconnect so old
Digest nonces expire. Authentication and the token are checked before
`Update.begin()` and authentication is checked again before accepting the final
request.

After writing, GlowLight runs the ESP-IDF image verifier over the complete target
partition. Truncated, interrupted, rejected and invalid uploads restore the
running partition as the boot target and do not trigger a restart.

`platformio.ini` explicitly selects the repository's `partitions.csv` layout
with two 1,280-KiB application slots. `make build-profiles` validates the OTA
metadata and rejects any firmware image larger than the smaller slot.

## Security Boundary

Digest authentication and the one-time token protect access and request replay,
but plain HTTP
does not encrypt the firmware body and does not provide trusted image signing.
Use OTA only on a trusted local network. An active network attacker could alter
traffic, and a syntactically valid malicious image would pass the ESP32 image
format checks.

Production deployments needing protection from an active LAN attacker require
signed images and ESP32 Secure Boot, ideally combined with flash encryption and
TLS. Those platform provisioning steps are intentionally outside this software
phase.

OTA processing uses Arduino's synchronous `WebServer`; animations, disconnect
detection and ESP-NOW application processing can pause while a request is being
parsed. The
running firmware remains in the other app slot until the full new image passes
`Update.end(true)`.

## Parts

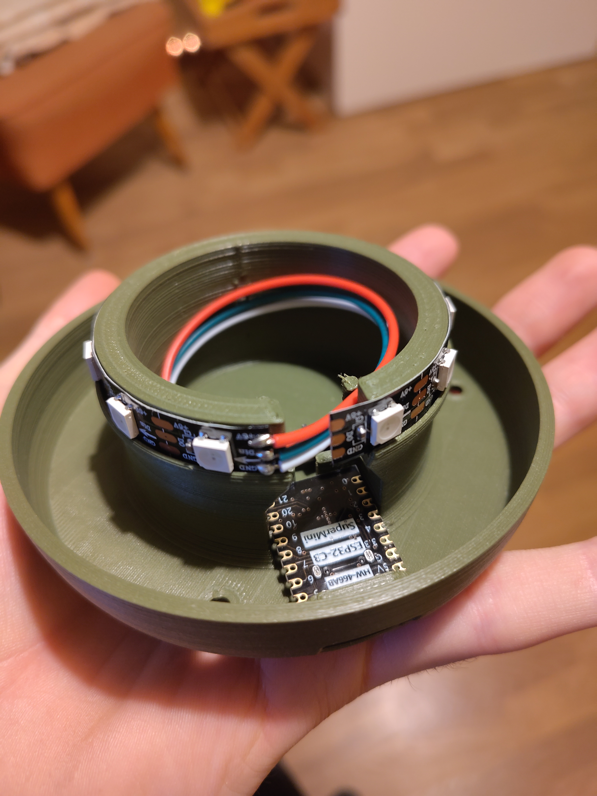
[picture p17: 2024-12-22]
media/images/components/inside.jpg

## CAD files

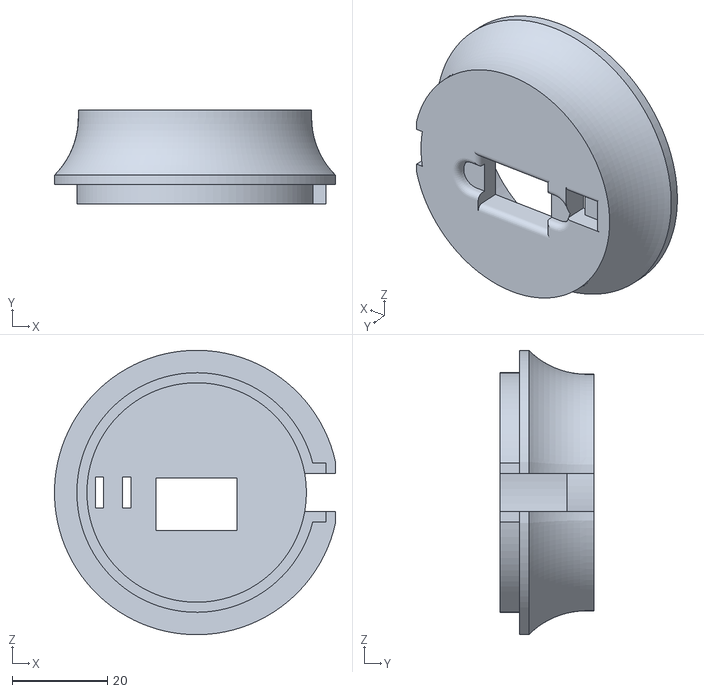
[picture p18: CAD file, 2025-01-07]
printing/inner-button-sensor.stl
58.9 x 19.6 x 59.6

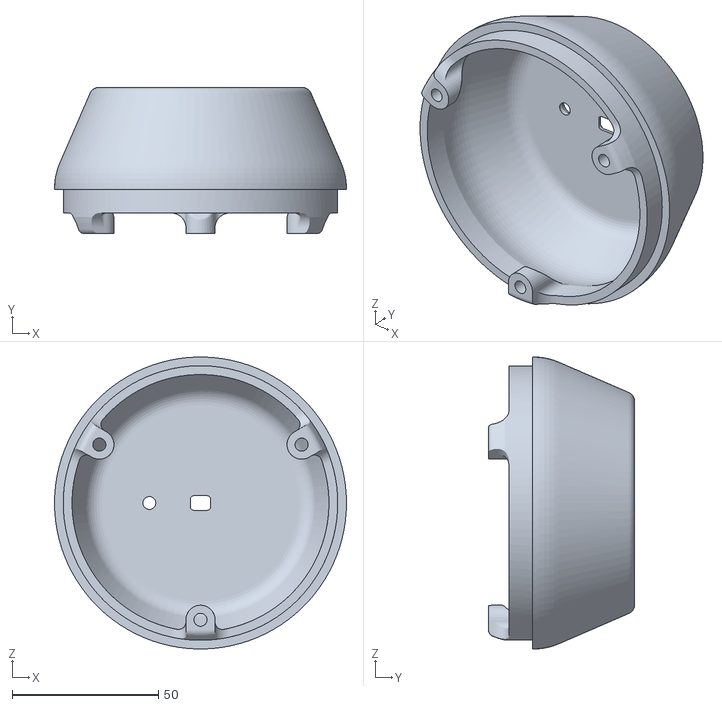
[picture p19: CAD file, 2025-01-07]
printing/top-cap-plain.stl
100.0 x 50.0 x 100.0

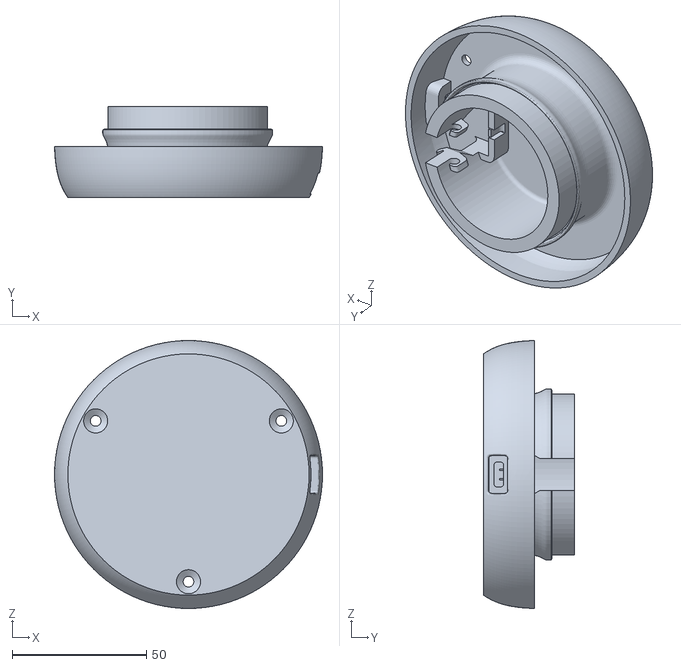
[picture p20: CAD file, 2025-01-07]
printing/base-usb-led.stl
100.0 x 34.0 x 100.0

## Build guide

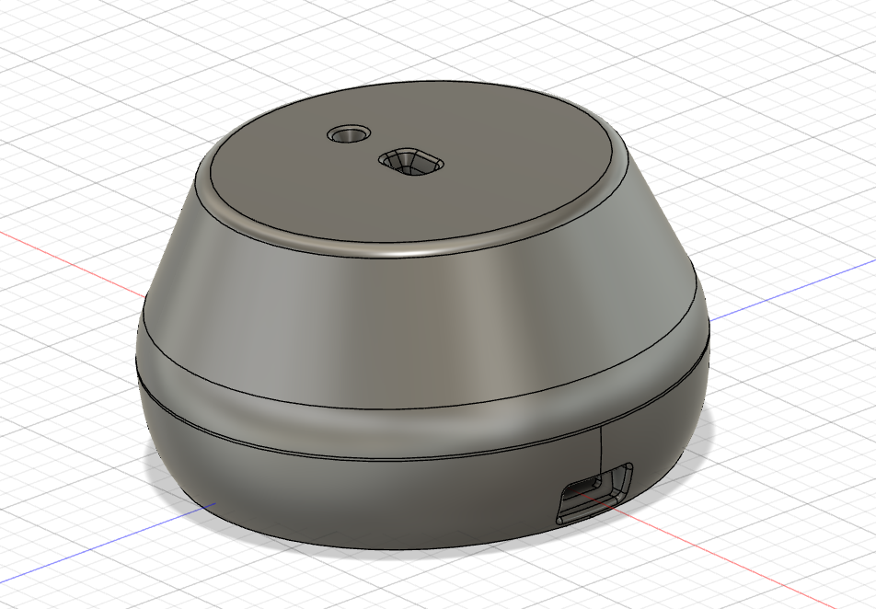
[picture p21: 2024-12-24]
media/images/printing/fusion360.png

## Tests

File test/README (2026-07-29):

# Tests

```bash
make test          # everything that runs without hardware (~1 s)
make test-native   # secure transport protocol tests only
make test-setup    # setup, group key handling, host-side frame format
```

## Native protocol and network tests (`test/native/`)

Compiles the real `lib/CommunicationService/CommunicationService.cpp` on the host
against thin shims for Arduino, WiFi, ESP-NOW and FreeRTOS, with the mbedTLS
subset it uses mapped onto OpenSSL. The logic under test is the firmware's own,
not a reimplementation.

Frames are crafted by `peer.cpp`, an independent implementation of the wire
format built directly on OpenSSL's HKDF and AES-GCM, so the firmware and the test
oracle cannot drift apart silently.

Covered:

- HKDF-SHA256 against the RFC 5869 vectors, AES-256-GCM against a NIST vector,
  and a golden frame that pins the exact bytes on the air
- tampering with every header field, the ciphertext and the GCM tag
- foreign group keys, plaintext legacy frames, truncated and oversized frames
- challenge/proof handshake, expired and unsolicited proofs, challenge replay
- replay window: duplicates, counters below the proof floor, counters outside the
  window, recordings replayed across a receiver reboot
- session lifecycle: peer reboot, replayed old-boot frames, eight-peer capacity,
  slot reclamation after the node timeout
- fragmentation: 1 to 3 fragments, the 512-byte maximum, out-of-order and
  duplicate fragments, missing fragments, non-canonical fragment sizes
- send path: counter monotonicity, oversized messages, full transmit queue,
  a lost send-completion callback
- discovery: only authenticated peers create nodes, timeouts, heartbeats
- WiFi state machine: fallback channel, timeouts, jittered reconnect backoff,
  targeted reconnects, mDNS lifecycle and radio API failures
- WiFi/ESP-NOW integration: dynamic peer channel and immediate HELLO after stable
  channel changes
- runtime configuration validation, secret redaction and captive-portal
  `WIFI_AP_STA` behavior on the ESP-NOW fallback channel
- OTA schema migration, independent password validation and redaction; firmware
  builds are bounded by the configured 1,280-KiB OTA app-slot size
- OTA server lifecycle, authentication and one-time token gates, flash failures,
  full ESP image verification and delayed successful restart
- registry schema export, strict setting validation, read-only values and atomic
  state application
- capability generation and generic controller operations for modes, options,
  settings and declared commands
- independent follow/publish policy, deterministic version conflicts, snapshots,
  detached local state and rejoin behavior

Run a subset:

```bash
make test-native FILTER=replay
./test/native/build/glow_native_tests --verbose counter_below
```

Requires OpenSSL headers (`libssl-dev`) and the PlatformIO library sources in
`.pio/libdeps/esp32c3` (`pio pkg install -e esp32c3`).

## Setup and frame format tests

`scripts/setup/tests/group_key_test.py` covers group key, portal-password and OTA
provisioning, redaction in every output path, file permissions and the shipped
template. `test/hil/glow_frames_test.py` pins the host-side frame builder used by
the hardware tests against the firmware's format.

## Two-lamp hardware integration test

Connect exactly two ESP32-C3 GlowLight lamps via USB and run:

```bash
make test-integration
```

The runner detects both `/dev/ttyACM*` devices, flashes the
`esp32c3-integration` profile, and verifies:

- mutual ESP-NOW discovery occurs exactly once
- mode changes propagate to the peer
- option changes propagate to the peer
- a detached lamp ignores group state, preserves local changes, and adopts the
  group snapshot when follow is re-enabled
- disabled publishing prevents local group changes from reaching the peer
- heartbeats do not create phantom nodes, crashes, or reboots

Both lamps must carry the same group key. Use already flashed integration
firmware with explicit ports:

```bash
python3 test/hil/two_lamp_sync.py --skip-flash --ports /dev/ttyACM0 /dev/ttyACM1
```

## Group isolation test

```bash
make test-isolation
```

Flashes the two lamps with **different** group keys and verifies that neither
authenticates or discovers the other and that a mode change does not cross the
group boundary. Afterwards both lamps are flashed back with the key from
`include/GlowConfig.h`, and the file is restored.

Note on log evaluation: both hardware runners only look at output after the
`Starting Glow` banner of the current run. Clearing the buffer on reset is not
enough, because the lamp keeps printing for a moment after the reset pulse and
lines already in the USB buffer arrive afterwards — a stale `Authenticated node`
line from the previous session would otherwise be read as a fresh one.

## Single-lamp security test on hardware

```bash
make test-security KEY=<64 hex characters>
```

Needs one lamp and the group key it was flashed with. Frames are built on the
host and pushed into the lamp through the `INJECT` console command, while `TRACE`
echoes the lamp's own frames so a full handshake can be completed without a
second radio. It verifies that foreign-key, tampered and unauthenticated traffic
is rejected, that recordings cannot be replayed after a handshake, and that a
replayed frame from an earlier boot session does not unseat the live peer.

`INJECT`, `TRACE`, `IDENTITY` and `NODES` exist only in the
`esp32c3-integration` profile and are compiled out of every production build.

## Home Assistant test on hardware

```bash
pip install paho-mqtt
make test-homeassistant BROKER=mqtt.local DEVICE=glow-1384610827 PORT=/dev/ttyACM0
```

Needs a lamp with MQTT enabled and the broker it publishes to. It checks that the
lamp announces its entities, that no payload leaks a secret, that a light command
is applied and reported back, and that the lamp stays healthy. With
`PEER_PORT=/dev/ttyACM1` it additionally verifies that a mode change sent to one
lamp reaches the second one over ESP-NOW.

The mapping between the control API and MQTT is covered by host tests in
`test/native/tests_homeassistant.cpp`, including the guardrail that a mode the
MQTT layer knows nothing about still appears with its options and settings.

## Firmware update test on hardware

```bash
export GLOW_OTA_PASSWORD=<the lamp's OTA password>
make test-ota PORT=/dev/ttyACM0 HOST=glowlight-52c82c.local
```

Needs one lamp with OTA enabled and reachable over the infrastructure WiFi. Each
lamp derives its own hostname, so take the name from its `Reachable as <name>.local`
log line rather than assuming `glowlight.local`. It
checks that the update page and the upload endpoint refuse unauthenticated and
wrongly authenticated requests, that a truncated or foreign image is rejected
and leaves the running firmware bootable, and that a valid image installs and
restarts the lamp. The serial port is only used to watch the lamp come back up.

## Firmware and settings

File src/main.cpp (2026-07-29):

#include <Arduino.h>
#include <Button2.h>
#include <Wire.h>

// Controller and services
#include "Controller.h"
#include "LightService.h"
#include "DistanceService.h"
#include <WiFi.h>

#include "NetworkService.h"
#include "CommunicationService.h"
#include "ConfigService.h"
#include "PreferencesConfigStore.h"
#include "CaptivePortalService.h"
#include "OtaService.h"
#include "HomeAssistantService.h"
#include "IntegrationConsole.h"
#include "ModeRegistration.h"

// Config
#include "GlowConfig.h"

// Shown as the device firmware version in Home Assistant.
#ifndef GLOW_FIRMWARE_VERSION
#define GLOW_FIRMWARE_VERSION "dev"
#endif

// Services
Button2 button;

LightService lightService;
NetworkService networkService;
CommunicationService communicationService;
DistanceService distanceService;
PreferencesConfigStore configStore;
CaptivePortalService captivePortalService;
OtaService otaService;
HomeAssistantService homeAssistantService;

// Controller
Controller controller(&distanceService, &communicationService);

/*
 * This is the main setup function; it is called only once during startup.
 */
void setup() {
#ifdef GLOW_INTEGRATION_TEST
  // A single injected ESP-NOW frame is a 507 character console line, which does
  // not fit the default receive buffer.
  Serial.setRxBufferSize(2048);
#endif
  Serial.begin(115200);

  // Setup I2C for the distance sensor
  Wire.begin(DISTANCE_SENSOR_SDA, DISTANCE_SENSOR_SCL);

  Serial.println("[INFO] Starting Glow");

  DeviceConfig deviceConfig = DeviceConfig::compileTimeDefaults();
  if (configStore.load(&deviceConfig)) {
    Serial.println("[INFO] Loaded persistent device configuration");
  } else {
    Serial.println("[INFO] Using compile-time device configuration");
  }
  String configError;
  if (!deviceConfig.validate(&configError)) {
    Serial.printf("[ERROR] Device configuration rejected: %s\n",
                  configError.c_str());
    deviceConfig = DeviceConfig::safeDefaults();
  }

  // Every lamp is flashed from the same configuration, so a default hostname
  // would be identical everywhere. Deriving it once here makes the mDNS name and
  // the Home Assistant device name unique, because both follow this value.
  uint8_t localMac[6] = {};
  WiFi.macAddress(localMac);
  deviceConfig.hostname = DeviceConfig::uniqueHostname(deviceConfig.hostname, localMac);

  NetworkConfig networkConfig;
  networkConfig.enabled = deviceConfig.wifiEnabled;
  networkConfig.ssid = deviceConfig.wifiSsid;
  networkConfig.password = deviceConfig.wifiPassword;
  networkConfig.hostname = deviceConfig.hostname;
  networkConfig.fallbackChannel = deviceConfig.fallbackChannel;

  pinMode(BUTTON_PIN, INPUT_PULLUP);
  bool portalRequested = GLOW_PORTAL_ENABLED && digitalRead(BUTTON_PIN) == LOW;
  String portalSsid = deviceConfig.hostname.substring(0, 26) + "-setup";

  // NetworkService owns the shared radio and must configure station mode before
  // ESP-NOW starts. Joining an access point continues asynchronously.
  lightService.setup();
  distanceService.setup();
  bool portalStarted = portalRequested &&
      networkService.setupProvisioning(networkConfig, portalSsid,
                                       GLOW_PORTAL_PASSWORD);
  if (!portalStarted) networkService.setup(networkConfig);

  CommunicationConfig communicationConfig;
  communicationConfig.enabled = deviceConfig.communicationEnabled;
  communicationConfig.groupKeyHex = deviceConfig.groupKeyHex;
  communicationService.setup(communicationConfig);
  networkService.onChannelChanged([](uint8_t channel) {
    communicationService.radioChannelChanged(channel);
    controller.requestResync();
  });

  button.begin(BUTTON_PIN);

  // Set debounce time (this is the time the button needs to be stable before a press is registered)
  button.setLongClickTime(500);

  registerModes(controller, lightService, distanceService, communicationService);

  // Setup controller
  controller.configureSyncDefaults(deviceConfig.syncFollow,
                                   deviceConfig.syncPublish);
  controller.configureRuntimeFeatures(GLOW_PORTAL_ENABLED,
                                      deviceConfig.otaEnabled);
  controller.setup();
  if (portalStarted) {
    captivePortalService.setup(configStore, networkService, deviceConfig);
  } else {
    OtaConfig otaConfig;
    otaConfig.enabled = deviceConfig.otaEnabled;
    otaConfig.password = deviceConfig.otaPassword;
    otaService.setup(networkService, otaConfig);

    // Home Assistant shares the infrastructure connection with OTA and is only
    // meaningful once the lamp is on the network, so it stays off in the portal.
    HomeAssistantConfig homeAssistantConfig;
    homeAssistantConfig.enabled = deviceConfig.mqttEnabled;
    homeAssistantConfig.host = deviceConfig.mqttHost;
    homeAssistantConfig.port = deviceConfig.mqttPort;
    homeAssistantConfig.user = deviceConfig.mqttUser;
    homeAssistantConfig.password = deviceConfig.mqttPassword;
    homeAssistantConfig.discoveryPrefix = deviceConfig.mqttDiscoveryPrefix;
    char deviceId[24];
    snprintf(deviceId, sizeof(deviceId), "glow-%u", communicationService.getNodeId());
    homeAssistantService.setup(networkService, controller, homeAssistantConfig,
                               deviceId, GLOW_FIRMWARE_VERSION);
  }

  // Configure button handlers
  button.setLongClickHandler([](Button2 &btn) {
    controller.nextMode();
  });

  button.setClickHandler([](Button2 &btn) {
    controller.nextOption();
  });

  // This click can be used for custom actions in the current mode
  button.setDoubleClickHandler([](Button2 &btn) {
    controller.customClick();
  });

  Serial.println("[INFO] GlowLight started");
}

/*
 * This is the main loop function; it is called repeatedly by the system.
 */
void loop() {
  // The services and controller need to be looped
  integrationConsoleLoop(controller, communicationService);
  button.loop();
  distanceService.loop();
  controller.loop();
  lightService.loop();
  networkService.loop();
  captivePortalService.loop();
  otaService.loop();
  homeAssistantService.loop();
  communicationService.loop();
}

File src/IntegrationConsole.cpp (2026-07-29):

#include "IntegrationConsole.h"

#include <Arduino.h>

#include "CommunicationService.h"
#include "Controller.h"

#ifdef GLOW_INTEGRATION_TEST
namespace {

// CONTROL requests are larger than raw ESP-NOW frame injection commands.
constexpr size_t MAX_COMMAND_LENGTH = 2048;

int hexNibble(char character) {
  if (character >= '0' && character <= '9') return character - '0';
  if (character >= 'a' && character <= 'f') return character - 'a' + 10;
  if (character >= 'A' && character <= 'F') return character - 'A' + 10;
  return -1;
}

// Feeds a raw frame into the receive path so a single lamp can be tested
// against replayed, tampered or foreign-key traffic without a second radio.
void handleInject(CommunicationService& communicationService, const String& hex) {
  size_t length = hex.length() / 2;
  if (hex.length() % 2 != 0 || length == 0 || length > ESP_NOW_MAX_DATA_LEN) {
    Serial.println("[TEST] ERROR|INJECT|LENGTH");
    return;
  }

  static uint8_t frame[ESP_NOW_MAX_DATA_LEN];
  for (size_t i = 0; i < length; ++i) {
    int high = hexNibble(hex[i * 2]);
    int low = hexNibble(hex[i * 2 + 1]);
    if (high < 0 || low < 0) {
      Serial.println("[TEST] ERROR|INJECT|HEX");
      return;
    }
    frame[i] = static_cast<uint8_t>((high << 4) | low);
  }

  // The radio reports the sender address; frames carry it in the header too.
  uint8_t sourceMac[6] = {};
  if (length >= 22) memcpy(sourceMac, frame + 16, sizeof(sourceMac));

  communicationService.injectRawFrame(sourceMac, frame, static_cast<int>(length));
  Serial.printf("[TEST] OK|INJECT|%u\n", static_cast<unsigned>(length));
}

void printJsonResponse(const char* label, const JsonDocument& document) {
  Serial.printf("[TEST] %s|", label);
  serializeJson(document, Serial);
  Serial.println();
}

void handleControl(Controller& controller, const String& json) {
  JsonDocument request;
  DeserializationError error = deserializeJson(request, json);
  if (error) {
    Serial.printf("[TEST] ERROR|CONTROL_JSON|%s\n", error.c_str());
    return;
  }
  printJsonResponse("CONTROL", controller.executeControl(request));
}

}  // namespace
#endif

void integrationConsoleLoop(Controller& controller,
                            CommunicationService& communicationService) {
#ifdef GLOW_INTEGRATION_TEST
  static String command;
  static bool overflowed = false;

  while (Serial.available() > 0) {
    char input = Serial.read();

    if (input == '\n') {
      command.trim();

      // A truncated line must be reported, not silently misinterpreted.
      if (overflowed) {
        Serial.println("[TEST] ERROR|OVERFLOW");
        command = "";
        overflowed = false;
        continue;
      }

      if (command == "PING") {
        Serial.println("[TEST] PONG");
      } else if (command == "STATUS") {
        String title = controller.getCurrentModeTitle();
        Serial.printf("[TEST] STATUS|%s|%u\n", title.c_str(), controller.getCurrentOption());
      } else if (command == "CAPABILITIES") {
        printJsonResponse("CAPABILITIES", controller.capabilities());
      } else if (command == "STATE") {
        printJsonResponse("STATE", controller.state());
      } else if (command.startsWith("CONTROL ")) {
        handleControl(controller, command.substring(8));
      } else if (command == "NEXT_MODE") {
        controller.nextMode();
        Serial.println("[TEST] OK|NEXT_MODE");
      } else if (command == "NEXT_OPTION") {
        controller.nextOption();
        Serial.println("[TEST] OK|NEXT_OPTION");
      } else if (command == "IDENTITY") {
        communicationService.printIdentity();
      } else if (command == "NODES") {
        communicationService.printNodes();
      } else if (command == "TRACE ON" || command == "TRACE OFF") {
        communicationService.setFrameTrace(command.endsWith("ON"));
        Serial.printf("[TEST] OK|%s\n", command.c_str());
      } else if (command.startsWith("INJECT ")) {
        handleInject(communicationService, command.substring(7));
      } else if (!command.isEmpty()) {
        Serial.printf("[TEST] ERROR|UNKNOWN_COMMAND|%s\n", command.c_str());
      }

      command = "";
    } else if (input != '\r') {
      if (command.length() < MAX_COMMAND_LENGTH) {
        command += input;
      } else {
        overflowed = true;
      }
    }
  }
#endif
}

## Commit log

2024-12-04 refactor: enhance LightService for smoother LED transitions and update MiniGame logic
2024-12-23 fix: update DistanceService to use Adafruit_VL53L0X and improve sensor initialization
2024-12-23 fix: enhance DistanceService logic for object detection and sensor configuration
2024-12-23 fix: streamline mode setup process in Controller
    [main.cpp]
2024-12-23 fix: update LED_NUM_LEDS and adjust speed settings for RainbowMode and BeaconMode
2024-12-23 fix: update hue value in BeaconMode and adjust README image attributes
    [main.cpp]
2025-01-01 add: 3d models
    [base-usb-led.stl, inner-button-sensor.stl, top-cap-plain.stl]
2025-01-01 docs: update README with beta version notice, enhance 3D printing section, and clarify pinout details
2025-01-01 fix: adjust diagram dimensions and add GND, 5V, and Din labels in GlowLight.drawio
2025-01-07 fix: update distance unchanged value and improve code comments in main setup and loop functions
    [main.cpp]
2025-01-14 fix: adjust LED update steps and add CommunicationService configuration parameters
2025-06-09 Add device management and serial monitor workflows
    - Implemented DeviceManagementWorkflow for scanning, displaying, and managing ESP32 devices.
    - Added functionality to show device information, test connections, and reset devices.
    - Created SerialMonitorWorkflow for real-time serial communication, logging, and advanced monitoring options.
    - Included user-friendly menus for device management and serial monitoring.
    - Enhanced error handling and troubleshooting tips for connection issues.
    - Introduced logging capabilities for monitoring sessions with options for filtering and timestamp formats.
    [ascii_art_fixed.py, config_manager.py, device_manager.py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]
2025-06-27 docs: Add technical diagrams to enhance understanding of system architecture and flow
2025-06-27 docs: Refine program flow diagrams for clarity and consistency in setup and execution details
2025-12-27 refactor: Remove debug print statements from various services and modes for cleaner output
2026-07-27 fix: stabilize synchronization and sensors
    [IntegrationConsole.cpp, config_manager.py, git_manager.py]
2026-07-29 feat: provision wifi, captive portal, ota and home assistant in the setup
    Adds the missing configuration steps to the interactive setup and makes
    install.sh use an existing checkout instead of always cloning into
    $HOME/GlowLight.
    Define values are now rendered from their Python type instead of a list of
    key names, so every string is quoted. The previous name-based approach wrote
    the MQTT broker host unquoted and broke the firmware build. Guard tests derive
    their expectations from GlowConfig.h-template, so a new setting that is not
    registered fails the tests rather than the build.
    All passwords are redacted in every output path, and Home Assistant can no
    longer be enabled without WiFi, a co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
    [config_manager.py, git_manager.py, validator.py]
2026-07-29 feat: add wifi, home assistant and password-protected ota to the firmware
    Hardens the encrypted ESP-NOW transport and opens the lamp towards the home
    network without giving up the group synchronization.
    Transport: the proof counter is now a real replay floor, a replayed frame from
    an earlier boot session can no longer unseat an authenticated peer, replayed
    challenges cannot be amplified into unlimited proofs, a lost send completion no
    longer silences the node, and session slots are reclaimed. A host test suite
    runs the real CommunicationService against thin Arduino, ESP-NOW, FreeRTOS and
    mbedTLS shims, with frames built by an independent implementation.
    Control: modes declare their options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
    [partitions.csv]
2026-07-29 test: add hardware test runners and make targets for the whole feature set
    Covers the encrypted transport against replayed and tampered frames on real
    hardware, group isolation between different keys, authenticated firmware
    updates and the Home Assistant integration against a broker.
    The group sync runner now works with any number of lamps instead of exactly
    two, so a group larger than a pair can be verified. Log evaluation is anchored
    to the boot banner of the current run, because a lamp keeps printing after the
    reset pulse and a stale line was read as a fresh one.
    make flash-all writes the same image to every connected lamp, which is what
    puts them into one group, and build-profiles chec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
    [glow_frames.py, glow_frames_test.py, home_assistant.py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]
2026-07-29 fix: connect home assistant to the loop and give every lamp its own hostname
    The MQTT service was created and configured but never ticked, so a lamp
    announced Home Assistant and then stayed silent: no connection attempt, no
    entities, nothing in Home Assistant. A missing loop call is not a compile
    error, which is why it went unnoticed.
    Lamps are flashed from one shared configuration, so a hostname left at its
    default was identical everywhere. It is the mDNS name and the Home Assistant
    device name at once, so every lamp claimed the same name and all devices showed
    up indistinguishable. A default hostname now carries the last three MAC bytes;
    a name entered in the portal belongs to that lamp a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
    [main.cpp, two_lamp_sync.py]
2026-07-29 docs: describe the new services, tooling and per-lamp naming
    The readme still advertised a mesh section that no longer exists and listed
    seven make targets out of eighteen. It now covers the encrypted group transport,
    the sync switches, WiFi, captive portal, OTA and Home Assistant, adds a table of
    what each library is responsible for, an index of the documentation and a short
    note on how the tests are built.
    The mode section gained what a new mode has to declare: the stable id next to
    the display title, and that registry keys, options and declared commands are
    what the control API and the Home Assistant entities are generated from.
    Hostnames are no longer fixed, so places that assumed glow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
2026-07-29 fix: let a colour be set instead of having it written back
    Setting the colour of "Static Light" over Home Assistant looked like a
    read-only field: the value arrived and was gone again a moment later. Two
    things caused it.
    The registry rejected any colour that was not exactly six bare hex digits, so
    the spelling a colour picker and a person both produce first, #FF8014, never
    reached it. Normalising a leading hash and surrounding whitespace now happens in
    GlowRegistry, not in one adapter, so the control API, the serial console and the
    group sync benefit from it as much as MQTT does.
    The heavier cause was the options of Static Light. They are presets that write
    their colour into the registry,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
    [ota_update.py]

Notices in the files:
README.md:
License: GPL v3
